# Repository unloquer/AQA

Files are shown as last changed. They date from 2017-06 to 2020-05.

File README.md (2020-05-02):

## Agentes de la Calidad del Aire (AQA)
Cuando se desea profundizar en el problema de la calidad del aire en Medellín nos encontramos con varios obstáculos debido a la complejidad del problema y la limitada capacidad de los ciudadanos para recolectar y examinar las mediciones.
El Kit AQA se esfuerza por acercar al ciudadano a la posibilidad de medir y analizar el aire que respira. De hecho, en las actividades propuestas se aprende a ensamblar un dispositivo para la medición del materialparticulado, y se considera unas herramientas para el estudio de las mediciones.
Es en los detalles del ensamblaje y el uso de las herramientas de análisis donde se puede pensar con las manos y entrar en relación directa con el problema de la calidad del aire.

## Instalación

descargar repositorio

          git clone https://github.com/unloquer/AQA.git

https://comunidad.unloquer.org/t/como-programar-el-aqa/33

## Enlaces
  * [Ejemplo de la trama de datos](https://raw.githubusercontent.com/daquina-io/VizCalidadAire/master/data/points.csv) https://raw.githubusercontent.com/daquina-io/VizCalidadAire/master/data/points.csv
  * [Foro](https://comunidad.unloquer.org/) comunidad unloquer  https://comunidad.unloquer.org/
  * [wiki](http://wiki.unloquer.org/personas/brolin/proyectos/agentes_calidad_aire) wiki unloquer http://wiki.unloquer.org/personas/brolin/proyectos/agentes_calidad_aire
  * [mapa de mediciones](http://daquina.io/aqaviz/) daquia.io http://daquina.io/aqaviz/
  * [Licensed under the TAPR Open Hardware License](www.tapr.org/OHL): www.tapr.org/OHL

## Como leer los colores
el color gradiente de los leds funciona mientras mas intenso el color mas contaminacion  y menos inteso el color  menos contaminacion

el color gradiente de los leds funciona mientras mas intenso el color mas contaminacion y menos inteso el color menos contaminacion 

color > 13 resultado genrlamente verde 

13 < color < 35 resultado  generamente amarillo

35 < color < 55 resultado  generalmente naranja

55 < color < 75 resultado  generalmente rojo

75 < color < 255 resultado  generalmente morado

color < 255 marron

## para donde van los datos

  * [mapa de mediciones](http://daquina.io/aqaviz/) daquia.io http://daquina.io/aqaviz/
  * [los dash board](http://aqa.unloquer.org:8888/sources/2/chronograf/data-explorer) chronograf http://aqa.unloquer.org:8888/sources/2/chronograf/data-explorer

## de donde vienen los datos de de difentes sensores como 

 * dht11 
 * plantower 
 * gps

## pines 
diagrama de pines

## como lo instalo 

[enlace a como instalarlo en comunidad unloquer](https://comunidad.unloquer.org/t/cargar-el-firmware-desde-linea-de-comando/118) 

## contacto 

 * irc --> #un/loquer
 * twitter --> [twitter de unloquer](https://twitter.com/unloquer?lang=es) enlace a https://twitter.com/unloquer?lang=es

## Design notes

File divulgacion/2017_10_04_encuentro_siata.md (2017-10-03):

# Encuentro con SIATA

## ¿Cómo estamos enfrentando el problema en un/loquer?
### El más bajo costo posible
### Comunidad alrededor del problema
  
  * ¿Blockchain? inmutable, consenso, retribución a los participantes
  
### Motivaciones
  * Tener datos para poder "jugar" 
  * Aprender de sensores y sistemas complejos
  
### Uso social de los de los datos como alternativa a la cultura de hacer emprendimientos comerciales de los datos

  * Permite acciones que respondan a necesidades directas (excursiones de toma de datos en situaciones críticas) 
  * Invitar a la acción colectiva a partir de los datos.

### Documentar con soberanía
  * facebook vs. datos publicos distribuidos
    - blockstack
    
### Gobierno distribuido

## Lo que nos gustaría aprender del SIATA
  * ¿Son reproducibles las nubecitas? (codigo abierto y diagrama de cableado)
  * ¿Vale la pena medir los gases?
  
## Propuestas
  * ¿Podríamos instalar uno de los sensores que estamos construyendo en una de las estaciones para comparar las mediciones? si usamos la ecuación descrita en https://en.wikipedia.org/wiki/Air_quality_index#Computing_the_AQI  podrían ser comparables las lecturas?

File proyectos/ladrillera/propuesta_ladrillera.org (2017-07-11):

* Agentes Calidad del Aire
** Justificación
   Medellín tiene un problema de calidad del aire, la política pública tiene planes a largo plazo, el sistema publico de monitoreo de calidad del aire tiene alcance limitado. 
** Problema
   El ciudadano no tiene una medición del aire que respira en el momento. 
** Solución propuesta
   Medidor portable que indique visualmente la calidad del aire y que permita socializar esas mediciones.
** Fases
*** Primer fase: 
**** Puntos fijos
**** con plataforma web de captura de datos,
**** alimentación de energía 
**** transmisión vía WiFi
**** (Opción almacenaje de datos en SD?)
**** Uso de los datos:
***** a. Publicación de dataset (Open Data), sin procesamiento o con depuración??
***** b. Publicación básica de resultados en web responsive, en mapas y capas de análisis básico.
**** Presupuesto fase 1:
     :LOGBOOK:
     CLOCK: [2017-07-10 Mon 17:40]--[2017-07-10 Mon 18:30] =>  0:50
     :END:
| Payee                                 | Account                                          | Amount   | Balance     |
| Sensor de partículas                  | fase1:costo:aparato:componente:sensor            | $ -20.00 | $ -20.00    |
| ESP8266                               | fase1:costo:aparato:componente:esp               | $ -10.00 | $ -30.00    |
| DHT (sensor de humedad y temperatura) | fase1:costo:aparato:componente:sensor:dht        | $ -0.65  | $ -30.65    |
| Leds                                  | fase1:costo:aparato:componente:feedback:led      | $ -0.16  | $ -30.81    |
| Alimentación Energía                  | fase1:costo:aparato:componente:energia:adaptador | $ -6.00  | $ -36.81    |
| Ensamblaje                            | fase1:costo:aparato:manoDeObra:ensamblaje        | $ -17.00 | $ -53.81    |
| Diseño electrónico                    | fase1:costo:aparato:manoDeObra:diseno            | $ -17.00 | $ -70.81    |
| Cableado                              | fase1:costo:aparato:manoDeObra:cableado          | $ -1.00  | $ -71.81    |
| Carcasa                               | fase1:costo:aparato:manoDeObra:diseno:carcasa    | $ -20.00 | $ -91.81    |
| Código                                | fase1:costo:aparato:manoDeObra:codigo            | $ -10.00 | $ -101.81   |
| Infraestructura                       | fase1:costo:aparato:infraestructura              | $ -12.00 | $ -113.81   |
|---------------------------------------+--------------------------------------------------+----------+-------------|
| Impuestos IVA 19%                     | fase1:costo:aparato:impuestos                    | $ -21.47 | $ -135.28   |
| Utilidad                              | fase1:costo:aparato:utilidad                     | $ -22.60 | $ -157.88   |
|---------------------------------------+--------------------------------------------------+----------+-------------|
|                                       |                                                  | Total    | $ -157.88   |

***  Segunda Fase: 
**** Puntos móviles con gps (Batería, 
**** transmisión vía WiFi o SimCard?, 
**** (opción de almacenar en SD).
**** Uso de los datos:
***** a. Publicación de dataset (Open Data), sin procesamiento o con depuración??
***** b. Publicación básica de resultados en web responsive, en mapas y capas de análisis básico.
***** c. Desarrollo de aplicación móvil (Android, posiblemente ios).
**** Presupuesto fase 2:
     :LOGBOOK:
     CLOCK: [2017-07-11 Tue 05:05]
     :END:
| Payee                                 | Account                                          | Amount   | Balance     |
| ESP8266                               | fase2:costo:aparato:componente:esp               | $ -10.00 | $ -10.00    |
| Sensor de partículas                  | fase2:costo:aparato:componente:sensor            | $ -20.00 | $ -30.00    |
| Gps                                   | fase2:costo:aparato:componente:gps               | $ -12.00 | $ -42.00    |
| DHT (sensor de humedad y temperatura) | fase2:costo:aparato:componente:sensor:dht        | $ -0.65  | $ -42.65    |
| Leds                                  | fase2:costo:aparato:componente:feedback:led      | $ -0.16  | $ -42.81    |
| Alimentación Energía                  | fase2:costo:aparato:componente:energia:adaptador | $ -6.00  | $ -48.81    |
| Batería                               | fase2:costo:aparato:componente:energia:bateria   | $ -6.00  | $ -54.81    |
| Ensamblaje                            | fase2:costo:aparato:manoDeObra:ensamblaje        | $ -17.00 | $ -71.81    |
| Diseño electrónico                    | fase2:costo:aparato:manoDeObra:diseno            | $ -17.00 | $ -88.81    |
| Cableado                              | fase2:costo:aparato:manoDeObra:cableado          | $ -1.00  | $ -89.81    |
| Carcasa                               | fase2:costo:aparato:manoDeObra:diseno:carcasa    | $ -20.00 | $ -109.81   |
| Código backend                        | fase2:costo:aparato:manoDeObra:codigo            | $ -10.00 | $ -119.81   |
| Análisis-Mapas                        | fase2:costo:servicio:analisis:mapas              | $ -10.00 | $ -129.81   |
| Aplicación móvil Android              | fase2:costo:servicio:aplicacion:android          | $ -10.00 | $ -139.81   |
| Lector memoria SD                     | fase2:costo:aparato:componente:lectorSD          | $ -0.66  | $ -140.47   |
| Infraestructura                       | fase2:costo:aparato:infraestructura              | $ -12.00 | $ -152.47   |
|---------------------------------------+--------------------------------------------------+----------+-------------|
| Impuestos IVA 19%                     | fase2:costo:aparato:impuestos                    | $ -28.88 | $ -181.35   |
| Utilidad                              | fase2:costo:aparato:utilidad                     | $ -30.40 | $ -211.75   |
|---------------------------------------+--------------------------------------------------+----------+-------------|
|                                       |                                                  | Total    | $ -211.75   |

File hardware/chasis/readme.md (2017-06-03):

Todos estos archivos abren con Solidworks y con Solidcam. Contactar a @rvega si necesitan el software o convertir de formato.

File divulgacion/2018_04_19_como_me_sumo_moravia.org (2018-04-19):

#+TITLE:      ¿Cómo me sumo?
#+AUTHOR:     son0p (Federico López)
#+EMAIL:      fede2001@gmail.com
#+INFOJS_OPT: view:t toc:t ltoc:t mouse:underline buttons:0 path:http://thomasf.github.io/solarized-css/org-info.min.js
#+HTML_HEAD: <link rel="stylesheet" type="text/css" href="http://thomasf.github.io/solarized-css/solarized-light.min.css" />
#+OPTIONS:    H:3 num:nil toc:t \n:nil ::t |:t ^:t -:t f:t *:t tex:t d:(HIDE) tags:not-in-toc
#+STARTUP:    align fold nodlcheck hidestars oddeven lognotestate
#+SEQ_TODO:   TODO(t) INPROGRESS(i) WAITING(w@) | DONE(d) CANCELED(c@)
#+LANGUAGE:   en
#+PRIORITIES: A C B
#+CATEGORY:   divulgacion

* ¿Cómo se esta sumando unloquer al problema de la calidad del aire?
** ¿Es relevante un dispositivo que le muestre a la *persona* la calidad del aire que respira en *ese  momento*?
** ¿De que sirve compartir esas mediciones a una red ciudadana?
*** ¿Los datos históricos me permiten enterarme de los momentos (meses, dias, horas) en que mejora la calidad del aire?
** ¿Qué poder tengo sobre mi aire?
*** ¿Las personas que estan tomando desiciones para cambiar esa situación estan muy lejos?
*** ¿A qué velocidad podemos esperar los cambios?
*** ¿Sirve la metáfora de la reja ? 
    Una persona habita con una ventana en un primer piso que da a la calle, a varios vecinos les han roto la ventana para robarles frutas y otras pertenencias, el gobierno dice que tiene pactos y programas para disminuír la delincuencia en la ciudad gradualmente hasta lograr índices parecidos a alguna ciudad tranquila de un país desarrollado, la persona no sabe si esperar a que el gobierno mejore la inseguridad o poner una reja en su ventana.
*** ¿La máscara sírve?                                                   
**** ¿Las partículas pm25 son mas pequeñas que un pelo de la nariz? 25 a 70 :log:
*** ¿Puedo saber dónde esta mejor el aire?

** ¿Puedo usar el pretexto del problema de la calidad del aire en medellín para aprender de  matemáticas?
*** ¿De Antropología?
**** ¿Es un problema nuevo en la ciudad? ¿no?  http://www.universocentro.com/NUMERO86/Humossetenteros.aspx
*** ¿De Programación?
*** ¿De Biología? 
**** El Guáimaro, Sogamoso https://actualidad.rt.com/actualidad/266121-arbol-magico-colombia-titan-polucion
** ¿Cómo me sumo?
*** ¿Puedo donar un sensor a un hospital infantil?
*** ¿Puedo resolver alguno de los problemas de programación?  https://github.com/unloquer/AQA/issues
*** ¿Puedo medir la calidad del aire en una fábrica cerca a mi casa?
*** ¿Puedo ayudar a saber si los foggers sirven para disminuir el material particulado?
*** ¿Puedo conversar sobre el tema en un foro? https://comunidad.unloquer.org/
* ------

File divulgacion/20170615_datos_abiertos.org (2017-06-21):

#+TITLE:      De los personal a lo colectivo
#+AUTHOR:     un/loquer
#+EMAIL:      unloquer@gmail.com
#+OPTIONS:    H:2 num:nil toc:t \n:nil ::t |:t ^:t -:t f:t *:t tex:t d:(HIDE) tags:not-in-toc
#+STARTUP:    align fold nodlcheck hidestars oddeven lognotestate
#+SEQ_TODO:   TODO(t) INPROGRESS(i) WAITING(w) | DONE(d) CANCELED(c)
#+TAGS:       Write(w) Update(u) Fix(f) Check(c) 
#+LANGUAGE:   es
#+PRIORITIES: A C B
#+CATEGORY:   un/loquer
#+CONSTANTS: d=298

** ¿Qué vamos a aprender hoy?
*** ¿Cómo en un/loquer se esta respondiendo ante el problema del aire?
**** ¿Artefacto para medir y reportar?
     Un dispositivo que permite hacer mediciones móviles.
***** ¿Microcontrolador? *ESP8266*
      Tiene conectividad wi-fi integrada, recive los datos de direferentes protocolos y genera la trama de datos.

|      lat |        lng | date      |        hour | altitude | course | speed | humidity | temperature | pm1 | pm25 | pm10 |
| 6.254207 | -75.575022 | 5/11/2017 | 05:54:00.00 |   1498.5 | 189.57 | 14.24 |     34.0 |        28.0 |  11 |   16 |   17 |
| 6.253995 | -75.575045 | 5/11/2017 | 05:54:05.00 |   1499.1 | 179.03 | 15.26 |     34.0 |        28.0 |  11 |   16 |   17 |
| 6.253763 | -75.575067 | 5/11/2017 | 05:54:11.00 |   1498.8 | 186.22 | 14.46 |     34.0 |        28.0 |  11 |   16 |   17 |
| 6.253593 | -75.575132 | 5/11/2017 | 05:54:16.00 |   1497.9 | 215.65 | 12.45 |     34.0 |        28.0 |  11 |   16 |   17 |
| 6.253485 | -75.575307 | 5/11/2017 | 05:54:22.00 |   1498.3 | 256.68 | 14.41 |     34.0 |        28.0 |  11 |   16 |   17 |
| 6.253502 | -75.575495 | 5/11/2017 | 05:54:27.00 |   1498.2 |  296.0 | 14.89 |     34.0 |        28.0 |  11 |   16 |   17 |

****** ¿Almacena los datos?
       Sí, porque no podemos garantizar conectividad wi-fi, se está trabajando en implementar el reporte a travéz de una red LoRa
***** ¿GPS?  *quectel l70*
      Entrega Timestamp, Latitud, Longitud, Altitud, Curso, y Velocidad, ver issue https://github.com/unloquer/AQA/issues/18
*****  ¿Sensor de partículas? *planttower PMSx003*
      Entrega mediciones de partículas pm1, pm2.5 y pm10.
***** ¿Sensor de temperatura y humedad? *DHT11*
***** ¿RGB Leds? 
      Retroalimentación visual expresada en colores ajustada a alguna escala.
***** TODO ¿Carcasa?
**** ¿Compartir los datos capturados?
*****  ¿Prueba de concepto? 
      Actualmente los datos se descargan de la memoria Flash de forma rudimentaria.
***** ¿Compartir la medición PM2.5 usando el ESSID?  
      Cualquier dispositivo Wi-Fi al alcance puede recibir el reporte de la medición en su listado de redes disponibles. https://github.com/unloquer/AQA/issues/14
***** TODO ¿Descarga con Wi-Fi?
      Requiere un navegador para conectar el ESP a alguna red disponible.
***** TODO ¿LoRa?
      Estamos en la búsqueda de unos gateway para hacer una prueba de concepto.
**** Detonantes:
***** Cuanto le vale a la ciudad darle información al individuo de su entorno vs. Cuanto le vale al individo generar esa info
***** ¿Aprendizaje a travez de problemas? *** ¿aprender? ¿en serio?
****** anarquía; no reconoce autoridad, paternalismo, ¿Qué hacemos?
****** varias ligas                                                     :Fix:
******* escala ciudad 
******* escala personal
*** ¿Qué puedo aprender con los datos que exponen?
**** dataPoints (advertencia!)  https://raw.githubusercontent.com/daquina-io/VizCalidadAire/master/data/points.csv
*****  ¿Porqué hay una medida de 500 !!! ¿subjetiva?
      Son datos sucios por diferentes razones, algunas ideas de depuración de @kleper https://github.com/daquina-io/VizCalidadAire/issues/2
****** ¿Cómo podemos calibrar? https://github.com/unloquer/AQA/issues/13
****** Link a mediciones mayores a 100 http://daquina.io/aqaviz/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
****** ¿Y si le agregamos un consenso? 
       Tener muchas mediciones del mismo sitio en diferentes días y horas permitiría ir validando los datos.
****** Gps 
       Emite datos errados cuando se está localizando, el asunto se esta tratando acá: https://github.com/unloquer/AQA/issues/18

**** Detonantes
***** ¿Puedo hacer mi propia comunidad de aire?
****** ¿Porque comunidades pequeñas?
***** ¿Puedo poner historias ?
*** ¿De qué me sirve los aspectos "abiertos" de lo que están haciendo?
**** ¿Respecto al Firmware? 
***** ¿Puedo adaptar el código a mis necesidades?
***** ¿Puedo quitar o agregar componentes (micrófono)?
**** ¿Respecto al Hardware?                                           :Check:
***** ¿Puedo cambiar el diseño PCB? ¿Para qué?
***** ¿Diseño sensor?                                                 :Check:
***** ¿Microcontrolador ESP2688?                                      :Check:
**** ¿Se puede alterar los datos?
***** ¿blame? ¿cadena de custodia? ¿blockchain?
**** ¿Porqué publican el presupuesto? https://github.com/unloquer/AQA/blob/master/costos.dat    

     | Dispositivo               | us$ |   col$ |
     |---------------------------+-----+--------|
     | DIY                       |  44 | 128876 |
     | Muñeco, cables a la vista | 108 | 316332 |
     | Embebido en carcasa       | 178 | 521362 |
     #+TBLFM: $3=$2*2929

**** Documentacion
***** Repositorio  https://github.com/unloquer/AQA
****** Fork
****** Clone
****** Pull request
****** Blame
***** Wiki http://wiki.unloquer.org/personas/brolin/proyectos/agentes_calidad_aire
**** Asuntos / issues / problemas https://github.com/unloquer/AQA/issues
**** ¿ lo puedo cerrar y vender?
***** ¿licenciar para mantener abierto?
****** ¿TAPR?  http://www.tapr.org/OHL
**** Detonantes
***** ¿Para que dure más de 100 años debe ser abierto o cerrado?

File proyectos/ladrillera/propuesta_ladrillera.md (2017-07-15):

<div id="table-of-contents">
<h2>Table of Contents</h2>
<div id="text-table-of-contents">
<ul>
<li><a href="#org6e1e0bf">1. Agentes Calidad del Aire</a>
<ul>
<li><a href="#org526cd84">1.1. Justificación</a></li>
<li><a href="#orge21955c">1.2. Problema</a></li>
<li><a href="#orgf99aaa4">1.3. Solución propuesta</a></li>
<li><a href="#org3859f35">1.4. Fases</a>
<ul>
<li><a href="#orgd3f207a">1.4.1. Primer fase:</a></li>
<li><a href="#org5c07fcc">1.4.2. Segunda Fase:</a></li>
</ul>
</li>
</ul>
</li>
</ul>
</div>
</div>

# Agentes Calidad del Aire

## Justificación

El Valle de Aburrá sufre un problema de acción colectiva en cuanto a la calidad del aire, pues, además de una topografía poco favorable para dispersar los gases contaminantes que la ciudad emite cada día, no existe un mecanismo que permita evidenciar el costo de las externalidades negativas por emisión de gases, así como los responsables directos de las mismas. Esto origina debilidad en el entendimiento del problema mismo, las políticas públicas no son capaces de hacer frente a la situación y se produce de forma generalizada la situación de "free-riders". La realidad es que no todos contaminamos igual, pero todos sí sufrimos las consecuencias de un aire en mal estado. 

Los efectos en la salud pública son la muestra más visible y urgente del problema. Estudios del Departamento Nacional de Planeación (DNP) revelan que la contaminación del aire urbano aporta el 75% de los gastos al sistema de salud colombiano por muertes y enfermedades asociadas a la degradación ambiental en Colombia, es decir, cerca de 15,4 billones de pesos. Esto significa 10 mil 527 personas entre 2015 y 2016 por esta causa. La ciudad con mayor número de casos es Medellín, con 2.105, que representan el 12,3 por ciento del total de las muertes que se presentan en esa ciudad. Esto representa un costo para la capital antioqueña de 2,8 billones de pesos, equivalentes al 5 por ciento del PIB de su Área Metropolitana. 

Las mediciones del Área Metropolitana del Valle de Aburrá muestran que 79% de las emisiones de PM 2.5, la partícula de contaminación más dañina para el ser humana, provienen de las fuentes móviles. Si bien se conoce que la solución de más impacto es la renovación del parque automotor más contaminante, el problema político inherente está en quién debe asumir el costo de esa renovación. Un primer paso está en el reconocimiento del problema, como ya hoy lo permite el Siata, pero este sistema de monitoreo es limitado pues no permite conocer el detalles claves del problema como los lugares precisos que presentan más contaminación, la calidad del aire que efectivamente están respirando las personas y los responsables directos. 

A raíz de esta situación, en marzo de 2017 el colectivo Datos y Gobierno Abierto Medellín realizó una jornada de trabajo durante el 'Open Data Day Medellin' (goo.gl/wacA5X), en la que se priorizaron los siguientes puntos como espacios de oportunidad para la generación de soluciones a la contaminación del aire:
1. La falta de información pública en términos de datos abiertos respecto a la calidad del aire y sus problemáticas conexas. Esto repercute en la dificultad para reconocer el problema y sus evidencias, además de hacer menos transparente el proceso de gestión de calidad del aire.
2. La falta de iniciativas pedagógicas dirigidas a la ciudadanía para que pueda aprender, comprender y proponer frente a la problemática actual del aire.
3. La falta de sensores y dispositivos ciudadanos de bajo costo que contribuyan a la captura, procesamiento y análisis de información sobre la calidad del aire.

## Problema

Con base en lo anterior, esta propuesta apunta a la generación de una solución para el ciudadano que no tiene una medición del aire que respira en el momento, así como la falta de datos de detalle sobre la calidad de aire que efectivamente respiran los habitantes de la ciudad. 

## Solución propuesta

Medidor portable que indique visualmente la calidad del aire y que permita agregar esas mediciones en una plataforma pública en línea con funcionalidades para el análisis de datos.

## Fases

### Primer fase:

1.  Puntos fijos

2.  con plataforma web de captura de datos,

3.  alimentación de energía

4.  transmisión vía WiFi

5.  (Opción almacenaje de datos en SD?)

6.  Uso de los datos:

    1.  a. Publicación de dataset (Open Data), sin procesamiento o con depuración??
    
    2.  b. Publicación básica de resultados en web responsive, en mapas y capas de análisis básico.

7.  Presupuesto fase 1:

    <table border="2" cellspacing="0" cellpadding="6" rules="groups" frame="hsides">

    <colgroup>
    <col  class="org-left" />
    
    <col  class="org-left" />
    
    <col  class="org-left" />
    
    <col  class="org-left" />
    </colgroup>
    <thead>
    <tr>
    <th scope="col" class="org-left">Payee</th>
    <th scope="col" class="org-left">Account</th>
    <th scope="col" class="org-left">Amount</th>
    <th scope="col" class="org-left">Balance</th>
    </tr>

    <tr>
    <th scope="col" class="org-left">Sensor de partículas</th>
    <th scope="col" class="org-left">fase1:costo:aparato:componente:sensor</th>
    <th scope="col" class="org-left">$ -20.00</th>
    <th scope="col" class="org-left">$ -20.00</th>
    </tr>

    <tr>
    <th scope="col" class="org-left">ESP8266</th>
    <th scope="col" class="org-left">fase1:costo:aparato:componente:esp</th>
    <th scope="col" class="org-left">$ -10.00</th>
    <th scope="col" class="org-left">$ -30.00</th>
    </tr>

    <tr>
    <th scope="col" class="org-left">DHT (sensor de humedad y temperatura)</th>
    <th scope="col" class="org-left">fase1:costo:aparato:componente:sensor:dht</th>
    <th scope="col" class="org-left">$ -0.65</th>
    <th scope="col" class="org-left">$ -30.65</th>
    </tr>

    <tr>
    <th scope="col" class="org-left">Leds</th>
    <th scope="col" class="org-left">fase1:costo:aparato:componente:feedback:led</th>
    <th scope="col" class="org-left">$ -0.16</th>
    <th scope="col" class="org-left">$ -30.81</th>
    </tr>

    <tr>
    <th scope="col" class="org-left">Alimentación Energía</th>
    <th scope="col" class="org-left">fase1:costo:aparato:componente:energia:adaptador</th>
    <th scope="col" class="org-left">$ -6.00</th>
    <th scope="col" class="org-left">$ -36.81</th>
    </tr>

    <tr>
    <th scope="col" class="org-left">Ensamblaje</th>
    <th scope="col" class="org-left">fase1:costo:aparato:manoDeObra:ensamblaje</th>
    <th scope="col" class="org-left">$ -17.00</th>
    <th scope="col" class="org-left">$ -53.81</th>
    </tr>

    <tr>
    <th scope="col" class="org-left">Diseño electrónico</th>
    <th scope="col" class="org-left">fase1:costo:aparato:manoDeObra:diseno</th>
    <th scope="col" class="org-left">$ -17.00</th>
    <th scope="col" class="org-left">$ -70.81</th>
    </tr>

    <tr>
    <th scope="col" class="org-left">Cableado</th>
    <th scope="col" class="org-left">fase1:costo:aparato:manoDeObra:cableado</th>
    <th scope="col" class="org-left">$ -1.00</th>
    <th scope="col" class="org-left">$ -71.81</th>
    </tr>

    <tr>
    <th scope="col" class="org-left">Carcasa</th>
    <th scope="col" class="org-left">fase1:costo:aparato:manoDeObra:diseno:carcasa</th>
    <th scope="col" class="org-left">$ -20.00</th>
    <th scope="col" class="org-left">$ -91.81</th>
    </tr>

    <tr>
    <th scope="col" class="org-left">Código</th>
    <th scope="col" class="org-left">fase1:costo:aparato:manoDeObra:codigo</th>
    <th scope="col" class="org-left">$ -10.00</th>
    <th scope="col" class="org-left">$ -101.81</th>
    </tr>

    <tr>
    <th scope="col" class="org-left">Infraestructura</th>
    <th scope="col" class="org-left">fase1:costo:aparato:infraestructura</th>
    <th scope="col" class="org-left">$ -12.00</th>
    <th scope="col" class="org-left">$ -113.81</th>
    </tr>
    </thead>
    
    <tbody>
    <tr>
    <td class="org-left">Impuestos IVA 19%</td>
    <td class="org-left">fase1:costo:aparato:impuestos</td>
    <td class="org-left">$ -21.47</td>
    <td class="org-left">$ -135.28</td>
    </tr>

    <tr>
    <td class="org-left">Utilidad</td>
    <td class="org-left">fase1:costo:aparato:utilidad</td>
    <td class="org-left">$ -22.60</td>
    <td class="org-left">$ -157.88</td>
    </tr>
    </tbody>
    
    <tbody>
    <tr>
    <td class="org-left">&#xa0;</td>
    <td class="org-left">&#xa0;</td>
    <td class="org-left">Total</td>
    <td class="org-left">$ -157.88</td>
    </tr>
    </tbody>
    </table>

### Segunda Fase:

1.  Puntos móviles con gps (Batería,

2.  transmisión vía WiFi o SimCard?,

3.  (opción de almacenar en SD).

4.  Uso de los datos:

    1.  a. Publicación de dataset (Open Data), sin procesamiento o con depuración??
    
    2.  b. Publicación básica de resultados en web responsive, en mapas y capas de análisis básico.
    
    3.  c. Desarrollo de aplicación móvil (Android, posiblemente ios).

5.  Presupuesto fase 2:

    <table border="2" cellspacing="0" cellpadding="6" rules="groups" frame="hsides">

    <colgroup>
    <col  class="org-left" />
    
    <col  class="org-left" />
    
    <col  class="org-left" />
    
    <col  class="org-left" />
    </colgroup>
    <thead>
    <tr>
    <th scope="col" class="org-left">Payee</th>
    <th scope="col" class="org-left">Account</th>
    <th scope="col" class="org-left">Amount</th>
    <th scope="col" class="org-left">Balance</th>
    </tr>

    <tr>
    <th scope="col" class="org-left">ESP8266</th>
    <th scope="col" class="org-left">fase2:costo:aparato:componente:esp</th>
    <th scope="col" class="org-left">$ -10.00</th>
    <th scope="col" class="org-left">$ -10.00</th>
    </tr>

    <tr>
    <th scope="col" class="org-left">Sensor de partículas</th>
    <th scope="col" class="org-left">fase2:costo:aparato:componente:sensor</th>
    <th scope="col" class="org-left">$ -20.00</th>
    <th scope="col" class="org-left">$ -30.00</th>
    </tr>

    <tr>
    <th scope="col" class="org-left">Gps</th>
    <th scope="col" class="org-left">fase2:costo:aparato:componente:gps</th>
    <th scope="col" class="org-left">$ -12.00</th>
    <th scope="col" class="org-left">$ -42.00</th>
    </tr>

    <tr>
    <th scope="col" class="org-left">DHT (sensor de humedad y temperatura)</th>
    <th scope="col" class="org-left">fase2:costo:aparato:componente:sensor:dht</th>
    <th scope="col" class="org-left">$ -0.65</th>
    <th scope="col" class="org-left">$ -42.65</th>
    </tr>

    <tr>
    <th scope="col" class="org-left">Leds</th>
    <th scope="col" class="org-left">fase2:costo:aparato:componente:feedback:led</th>
    <th scope="col" class="org-left">$ -0.16</th>
    <th scope="col" class="org-left">$ -42.81</th>
    </tr>

    <tr>
    <th scope="col" class="org-left">Alimentación Energía</th>
    <th scope="col" class="org-left">fase2:costo:aparato:componente:energia:adaptador</th>
    <th scope="col" class="org-left">$ -6.00</th>
    <th scope="col" class="org-left">$ -48.81</th>
    </tr>

    <tr>
    <th scope="col" class="org-left">Batería</th>
    <th scope="col" class="org-left">fase2:costo:aparato:componente:energia:bateria</th>
    <th scope="col" class="org-left">$ -6.00</th>
    <th scope="col" class="org-left">$ -54.81</th>
    </tr>

    <tr>
    <th scope="col" class="org-left">Ensamblaje</th>
    <th scope="col" class="org-left">fase2:costo:aparato:manoDeObra:ensamblaje</th>
    <th scope="col" class="org-left">$ -17.00</th>
    <th scope="col" class="org-left">$ -71.81</th>
    </tr>

    <tr>
    <th scope="col" class="org-left">Diseño electrónico</th>
    <th scope="col" class="org-left">fase2:costo:aparato:manoDeObra:diseno</th>
    <th scope="col" class="org-left">$ -17.00</th>
    <th scope="col" class="org-left">$ -88.81</th>
    </tr>

    <tr>
    <th scope="col" class="org-left">Cableado</th>
    <th scope="col" class="org-left">fase2:costo:aparato:manoDeObra:cableado</th>
    <th scope="col" class="org-left">$ -1.00</th>
    <th scope="col" class="org-left">$ -89.81</th>
    </tr>

    <tr>
    <th scope="col" class="org-left">Carcasa</th>
    <th scope="col" class="org-left">fase2:costo:aparato:manoDeObra:diseno:carcasa</th>
    <th scope="col" class="org-left">$ -20.00</th>
    <th scope="col" class="org-left">$ -109.81</th>
    </tr>

    <tr>
    <th scope="col" class="org-left">Código backend</th>
    <th scope="col" class="org-left">fase2:costo:aparato:manoDeObra:codigo</th>
    <th scope="col" class="org-left">$ -10.00</th>
    <th scope="col" class="org-left">$ -119.81</th>
    </tr>

    <tr>
    <th scope="col" class="org-left">Análisis-Mapas</th>
    <th scope="col" class="org-left">fase2:costo:servicio:analisis:mapas</th>
    <th scope="col" class="org-left">$ -10.00</th>
    <th scope="col" class="org-left">$ -129.81</th>
    </tr>

    <tr>
    <th scope="col" class="org-left">Aplicación móvil Android</th>
    <th scope="col" class="org-left">fase2:costo:servicio:aplicacion:android</th>
    <th scope="col" class="org-left">$ -10.00</th>
    <th scope="col" class="org-left">$ -139.81</th>
    </tr>

    <tr>
    <th scope="col" class="org-left">Lector memoria SD</th>
    <th scope="col" class="org-left">fase2:costo:aparato:componente:lectorSD</th>
    <th scope="col" class="org-left">$ -0.66</th>
    <th scope="col" class="org-left">$ -140.47</th>
    </tr>

    <tr>
    <th scope="col" class="org-left">Infraestructura</th>
    <th scope="col" class="org-left">fase2:costo:aparato:infraestructura</th>
    <th scope="col" class="org-left">$ -12.00</th>
    <th scope="col" class="org-left">$ -152.47</th>
    </tr>
    </thead>
    
    <tbody>
    <tr>
    <td class="org-left">Impuestos IVA 19%</td>
    <td class="org-left">fase2:costo:aparato:impuestos</td>
    <td class="org-left">$ -28.88</td>
    <td class="org-left">$ -181.35</td>
    </tr>

    <tr>
    <td class="org-left">Utilidad</td>
    <td class="org-left">fase2:costo:aparato:utilidad</td>
    <td class="org-left">$ -30.40</td>
    <td class="org-left">$ -211.75</td>
    </tr>
    </tbody>
    
    <tbody>
    <tr>
    <td class="org-left">&#xa0;</td>
    <td class="org-left">&#xa0;</td>
    <td class="org-left">Total</td>
    <td class="org-left">$ -211.75</td>
    </tr>
    </tbody>
    </table>

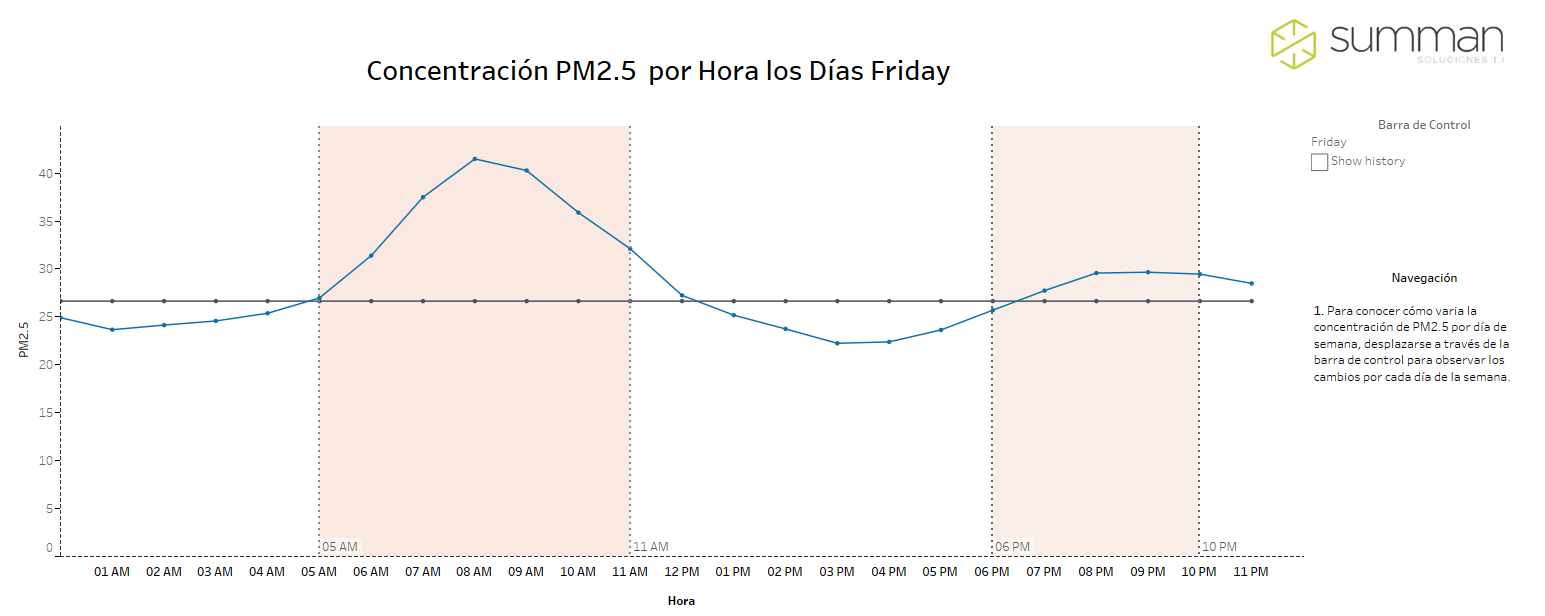
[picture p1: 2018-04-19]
divulgacion/assets/img/Día y Hora.png

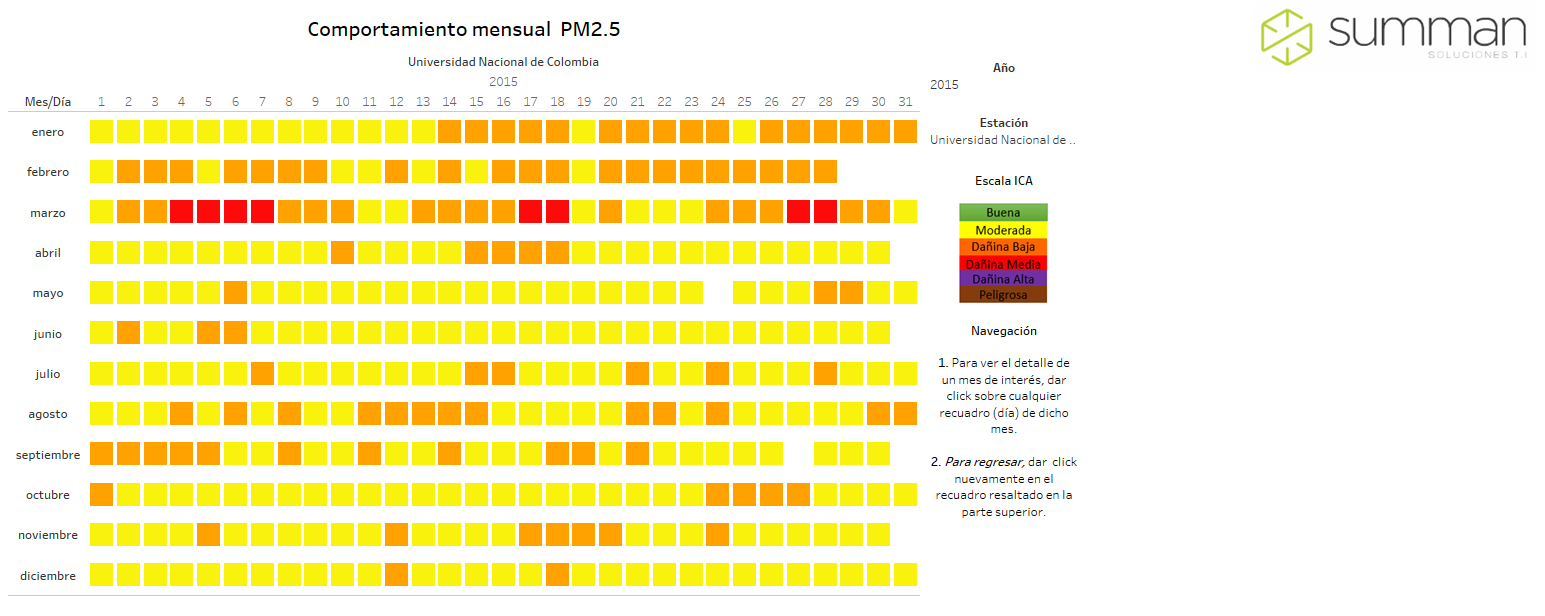
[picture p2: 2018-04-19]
divulgacion/assets/img/mes_dias.png

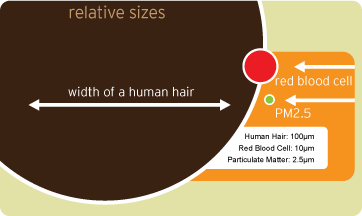
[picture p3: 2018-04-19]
divulgacion/assets/img/air-we-breathe-pm25.gif

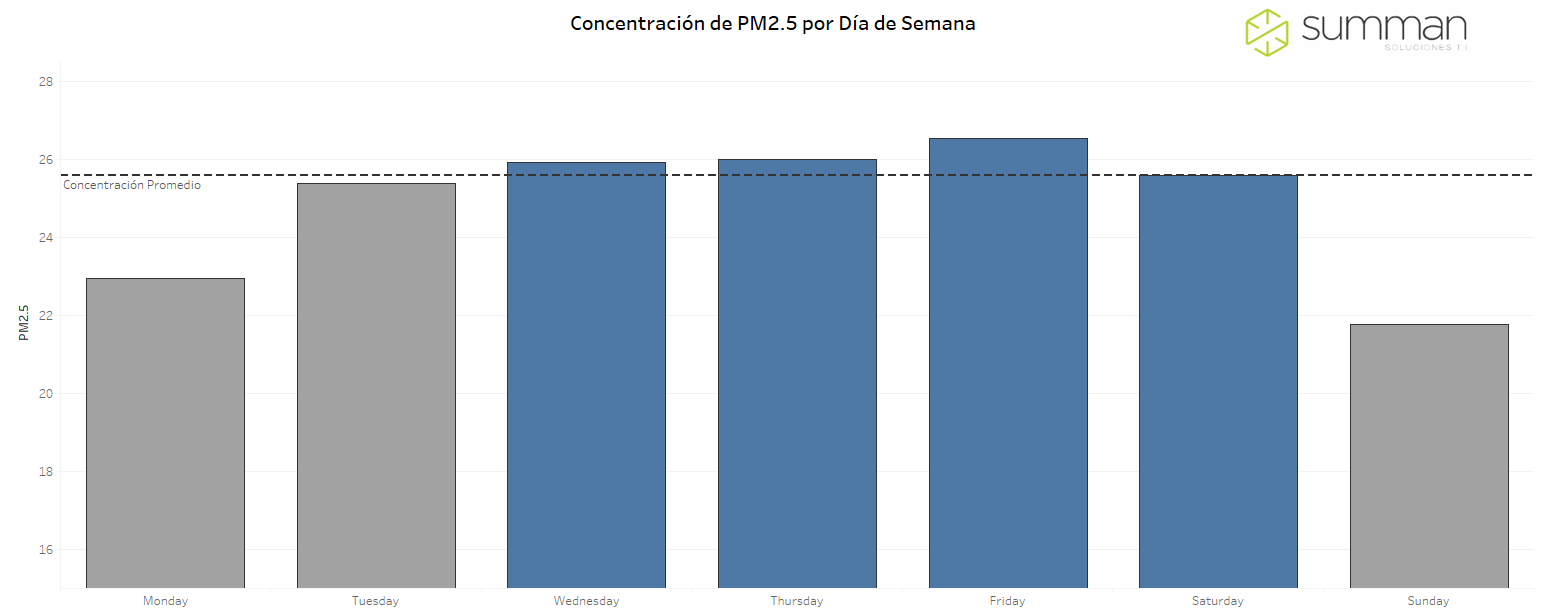
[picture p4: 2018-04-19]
divulgacion/assets/img/Semana.png

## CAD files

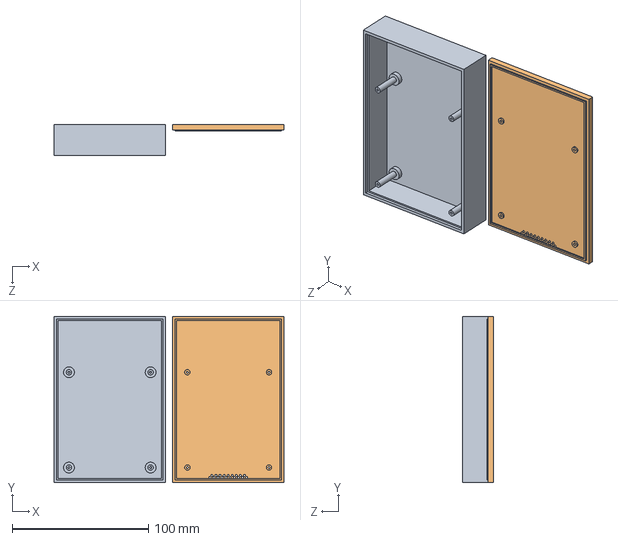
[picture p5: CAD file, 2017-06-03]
hardware/chasis/Maquinado CAM/Ensamble CAM.SLDASM
169.0 x 122.0 x 23.0 mm
Tapa1
Tapa2

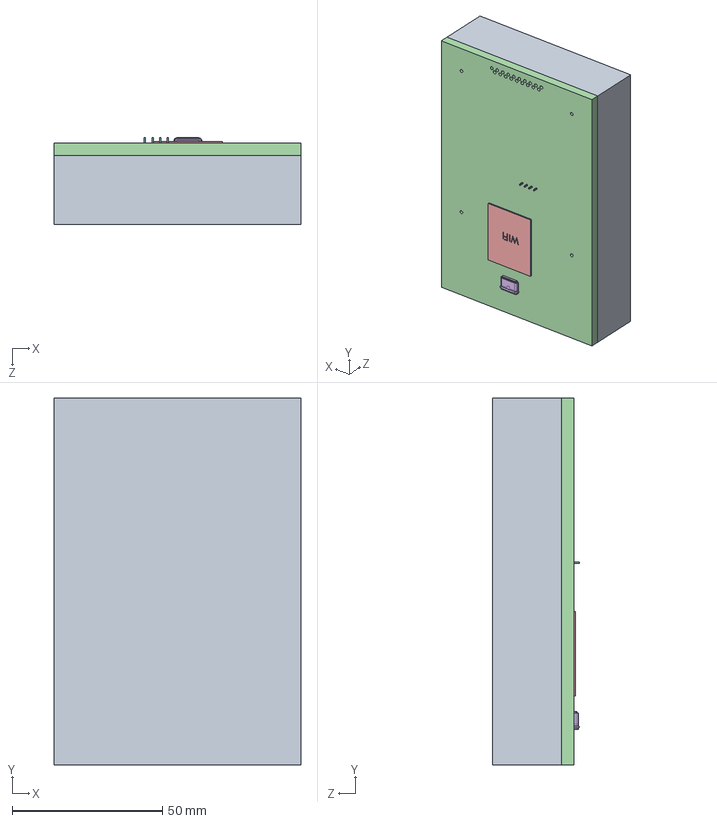
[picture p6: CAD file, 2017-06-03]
hardware/chasis/Modelo CAD/Ensamble.SLDASM
82.0 x 122.0 x 28.9 mm
Sensor
PCB
USB
GPS
DHT11

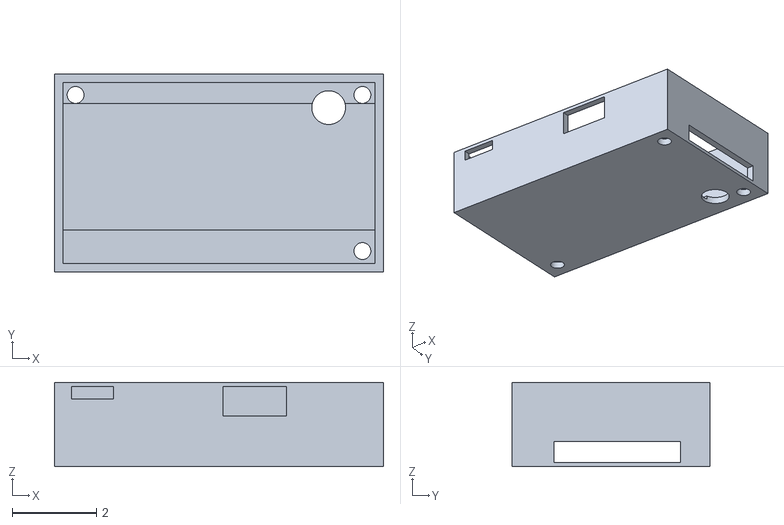
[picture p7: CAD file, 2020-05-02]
hardware/chasis/chasis_tarjeta_roja/aqacarcasa.stl
7.80 x 4.70 x 2.00

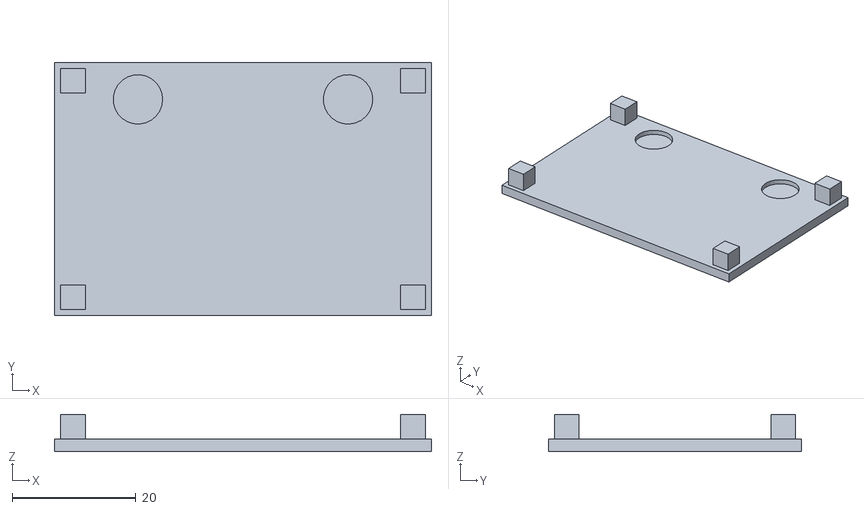
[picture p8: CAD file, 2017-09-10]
hardware/chasis/ChasisAQAFreecad/TapaChasisAQA2.stl
61.0 x 41.0 x 6.00

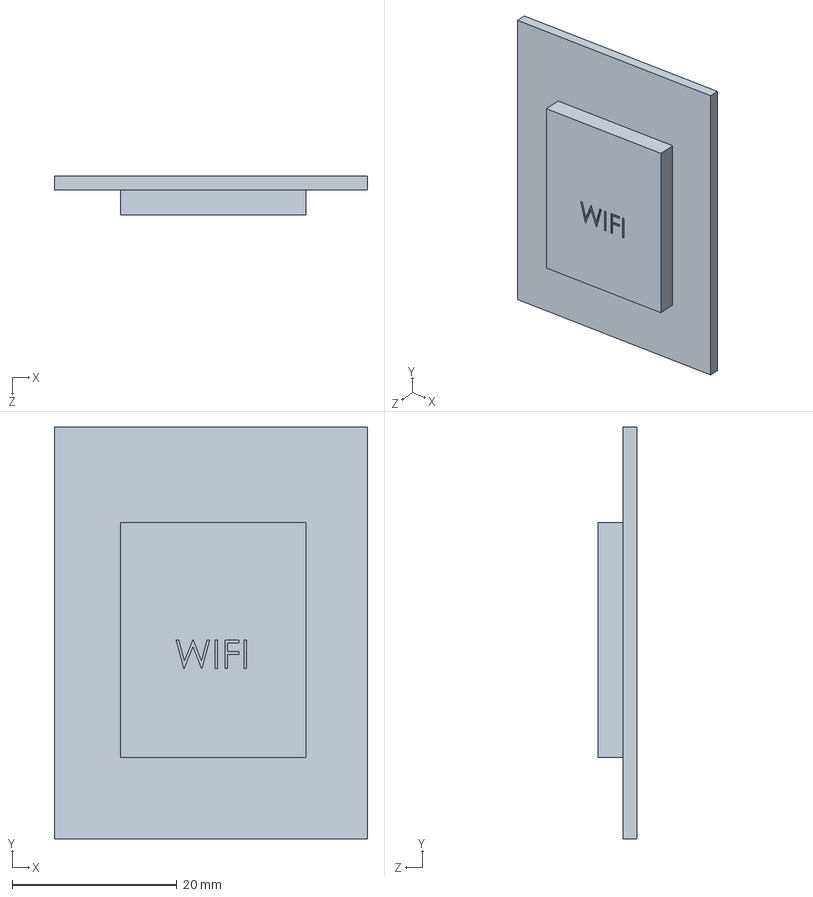
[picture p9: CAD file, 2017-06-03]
hardware/chasis/Modelo CAD/PCB.SLDPRT
38.0 x 50.0 x 4.70 mm

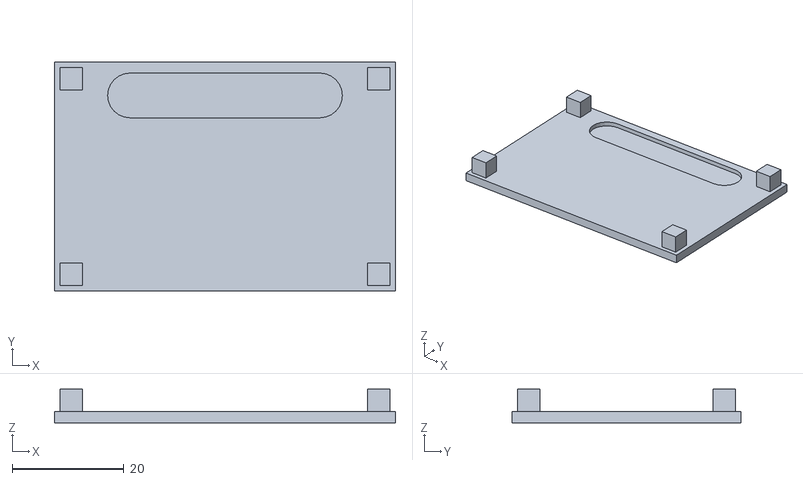
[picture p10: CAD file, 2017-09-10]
hardware/chasis/ChasisAQAFreecad/TapaChasisAQA3.stl
61.0 x 41.0 x 6.00

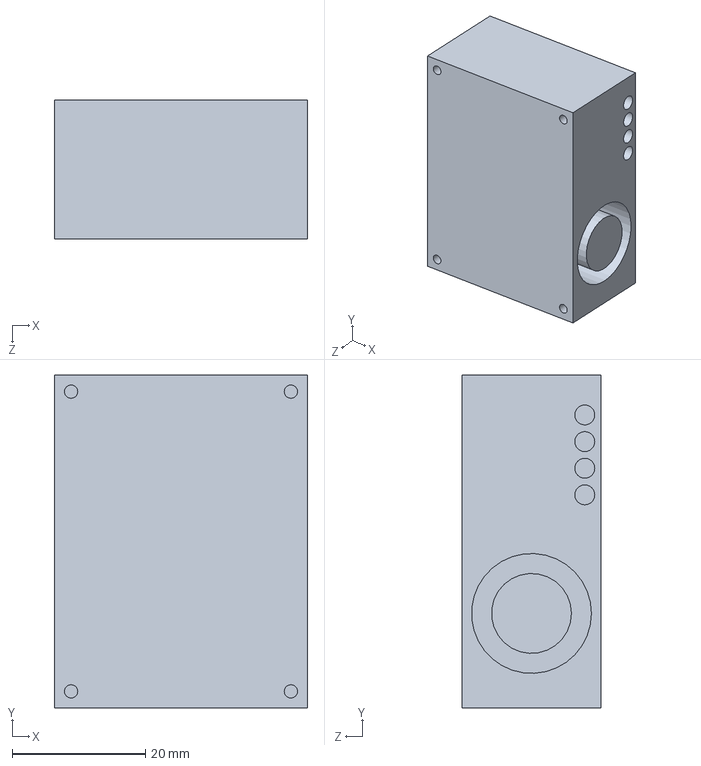
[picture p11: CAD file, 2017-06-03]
hardware/chasis/Modelo CAD/Sensor.SLDPRT
38.0 x 50.0 x 20.9 mm

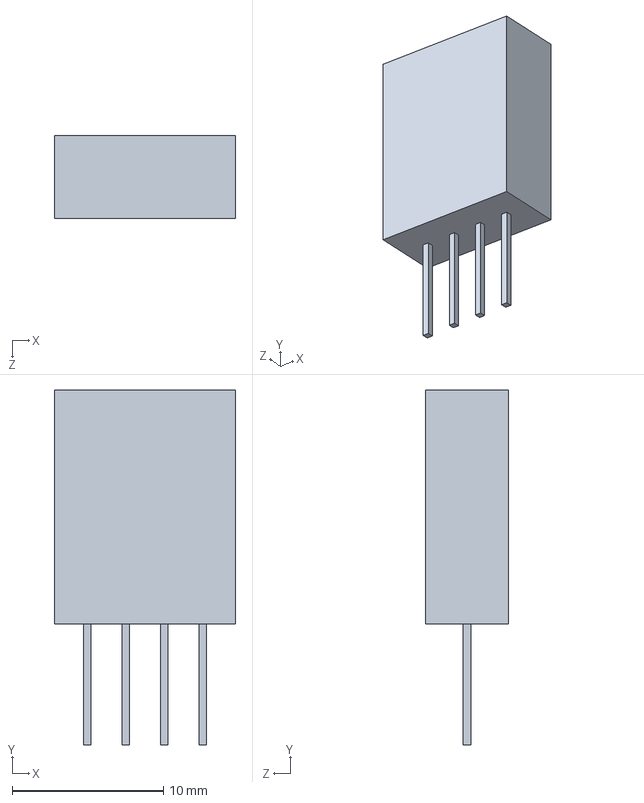
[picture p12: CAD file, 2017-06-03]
hardware/chasis/Modelo CAD/DHT11.SLDPRT
12.0 x 23.5 x 5.50 mm

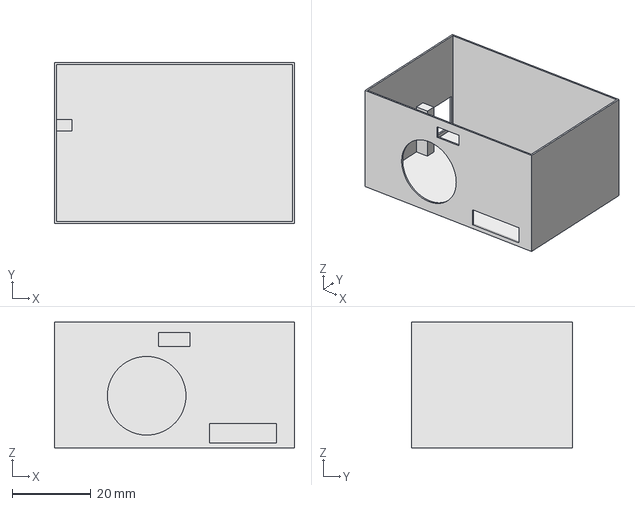
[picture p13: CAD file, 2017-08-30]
hardware/chasis/ChasisAQAFreecad/ChasisAQA.fcstd
61.0 x 41.0 x 32.0 mm

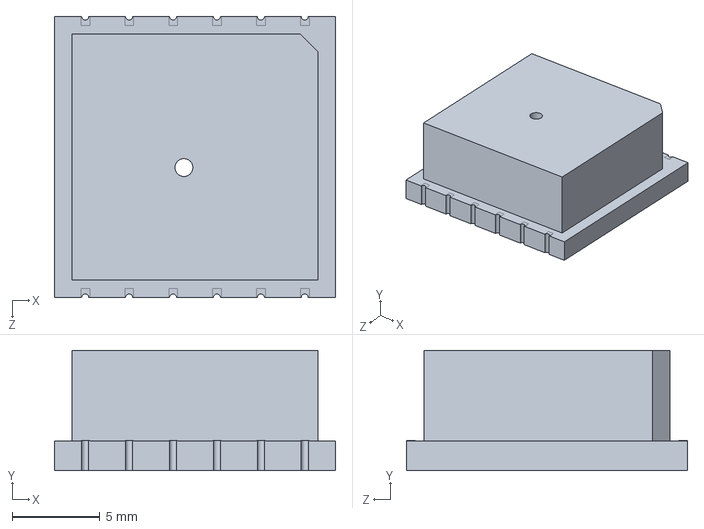
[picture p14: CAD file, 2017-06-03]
hardware/chasis/Modelo CAD/GPS.SLDPRT
16.0 x 6.85 x 16.0 mm

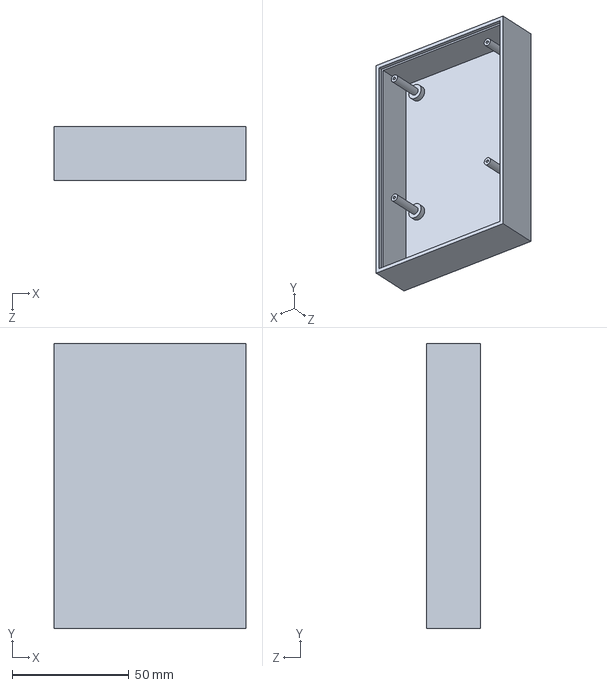
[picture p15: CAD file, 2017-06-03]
hardware/chasis/Modelo CAD/Tapa1.SLDPRT
82.0 x 122.0 x 23.0 mm

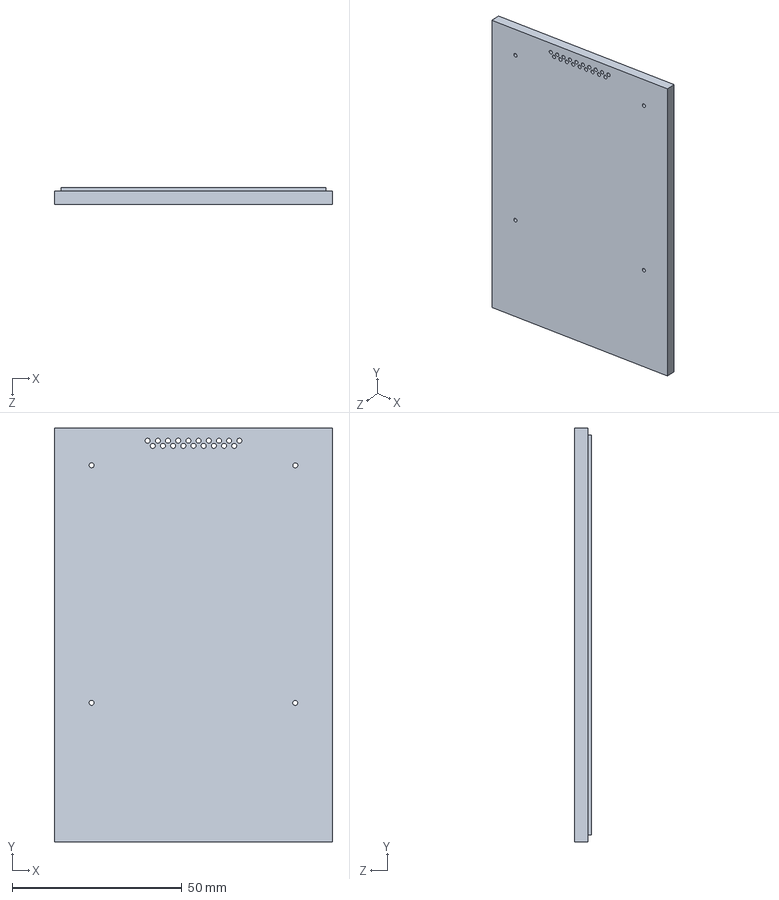
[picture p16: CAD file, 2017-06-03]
hardware/chasis/Modelo CAD/Tapa2.SLDPRT
82.0 x 122.0 x 5.00 mm

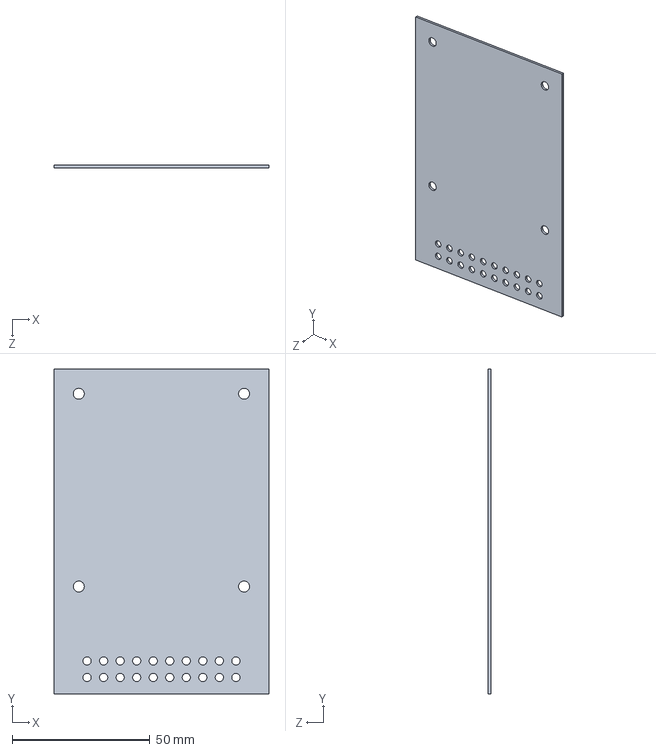
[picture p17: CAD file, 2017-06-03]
hardware/chasis/Modelo CAD/Tapa3.SLDPRT
78.0 x 118.0 x 1.00 mm

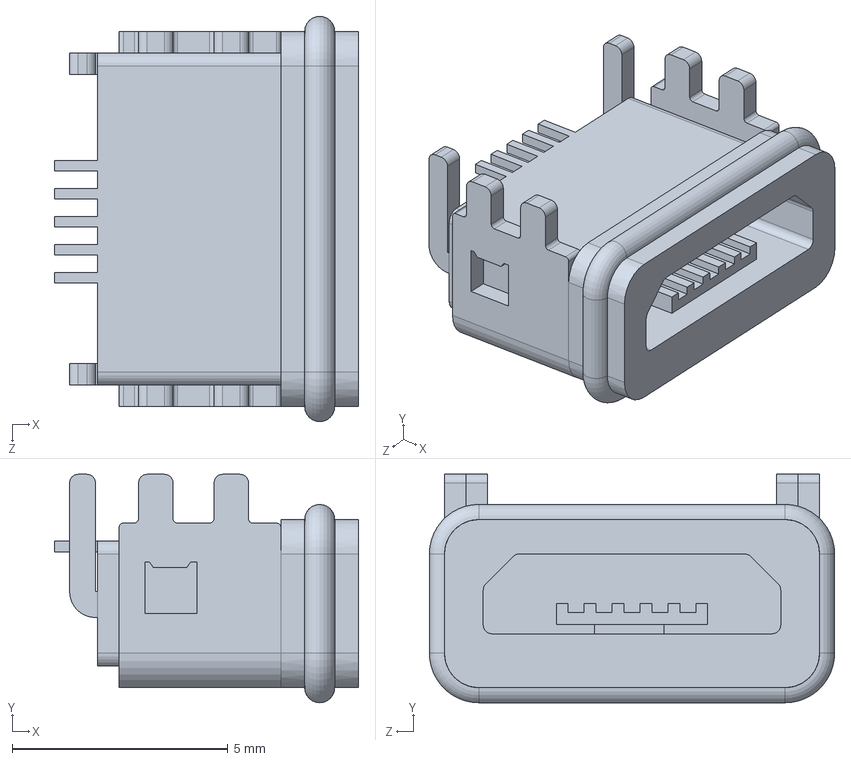
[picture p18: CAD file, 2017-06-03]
hardware/chasis/Modelo CAD/USB.sldprt
7.05 x 5.30 x 9.40 mm

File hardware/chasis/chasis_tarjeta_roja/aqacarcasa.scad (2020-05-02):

//no funciono la primera vez que se imprimo por tiempo por que quedo medio impreso 
difference(){
union(){
difference(){
union (){
large= 76;//las medidas de largo del sensor
largo = large+8;//cambio las variables de nombre para que las leea el codigo=84
deep=45;
profundo = deep+5;//50
 paredes=2;
 alto=20;
 tornilloyuno =  44.5;
cube([largo,profundo,paredes]);//base
//translate([0,0,2])//acrilico
//color("blue",0.7)//acrilico
//cube([large,4.7,0.2]);//acrilico
cube([largo,paredes,alto]);//lado  frente
translate([0,profundo,0])//lado trasero
cube([largo,paredes,alto]);//lado  trasero
cube([paredes,profundo,alto]);//lado 1 para micro usb
translate([largo,0,0])//lado 1 para mini usb
cube([paredes,profundo+2,alto]);//lado 1 para mini usb
}translate([-1,5,1])
cube([90,40,7]);}}
union(){
translate([67,39,-1])//grande
cylinder(r=4 ,h=3, $fn=100);}//grande
translate([77,44.5,-1])//pequño y2 x2
cylinder(r=2 ,h=3, $fn=100);
translate([9,44.5,-1])
//pequño y2 x1
cylinder(r=2 ,h=3, $fn=100);
//pequño y1 x2
translate([77,5,-1])
cylinder(r=2 ,h=3, $fn=100);
translate([30,-1,12])
cube ([15,4,7]);
translate([4,-1,16])
cube ([15,5,3]);
}

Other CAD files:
hardware/chasis/ChasisAQAFreecad/TapaChasisAQA.fcstd
hardware/chasis/Modelo CAD/ESP.SLDPRT
hardware/chasis/ChasisAQAFreecad/ChasisAQA.stl
hardware/chasis/ChasisAQAFreecad/TapaChasisAQA.stl

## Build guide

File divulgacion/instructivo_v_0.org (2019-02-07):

#+TITLE:      Instructivo
#+AUTHOR:     unloquer
#+EMAIL:      unloquer@gmail.com
#+INFOJS_OPT: toc:nil mouse:underline buttons:0 path:http://thomasf.github.io/solarized-css/org-info.min.js
#+HTML_HEAD: <link rel="stylesheet" type="text/css" href="http://thomasf.github.io/solarized-css/solarized-light.min.css" />
#+OPTIONS:    H:3 num:nil toc:t \n:nil ::t |:t ^:t -:t f:t *:t tex:t d:(HIDE) tags:not-in-toc
#+STARTUP:    align fold nodlcheck hidestars oddeven lognotestate
#+SEQ_TODO:   TODO(t) INPROGRESS(i) WAITING(w@) | DONE(d) CANCELED(c@)
#+LANGUAGE:   en
#+PRIORITIES: A C B
#+CATEGORY:   divulgacion

* Ambientación

** ¿Es la primera vez en un taller sobre la calidad del aire?
** ¿Qué se espera encontrar en este taller? 
** ¿Se ha ido a otro taller de calidad del aire? ¿Qué se ha encontrado?
** Lo que se puede y lo que no
*** Si se puede
**** Equivocarse
**** Jugar
**** Apasionarse por algún conocimiento o por alguna persona
**** Cuestionar
**** _____________
**** _____________
*** No se puede
**** Trollear (provocar reacciones emotivas en el otro)
**** Imponer una posición frente a un tema
**** __________
**** __________
* Nivel 1: Escala de colores

** Introducción 
    Camiones, carros, fábricas, emiten contaminantes pequeños que están en el aire y se mueven con el viento, 
***** ¿Cómo se puede saber de las zonas de mayor concentración de ese material particulado? 
***** ¿Cómo se puede visualizar?
***** ¿Porqué es importante que los ciudadanos midan la calidad del aire?
** ¿Se puede medir el aire que está alrededor?
   Imprime un mapa del barrio, sale a caminar con marcadores verde, naranja, rojo, morado y marrón, marca las mediciones en el mapa. 
***** Pasa cerca al mofle de un carro y observa el cambio en los colores.
***** ¿Qué pasa con las medicines en un semáforo cuando se acumulan carros intermitentemente?
***** ¿Cuáles son las zonas de mayor concentración de material particulado en mi cuadra? 
** Desde la posición de quien respira ¿existe diferencia entre la presencia del material particulado que hay a nivel atmosférico y las emisiones cercanas ?
** ¿Se puede ensamblar un sensor portable para medir la presencia (de particulas pequeñas) en el aire ?
***** PRACTICA: Poner a funcionar el sensor, 
      Partes: <sensor partículas> <microcontrolador> <leds> <pila> <hoja de papel> <colores>
****** Ensamble la pieza <sensor> en la pieza <microcontrolador>
****** Ensamble la pieza <leds> en la pieza <microcontrolador> 
****** Para encender, conecte el <microcontrolador> con el <adaptador USB>
****** Tome nota de los colores cada minuto en un papel durante 15 minutos
****** Experimentos
******* Enciende un fosforo cerca al sensor y toma nota de los cambios en la escala de colores.
******* En una habitación compara las mediciones cerrando ventanas y puertas con las que se observan con puertas y ventanas 
* Nivel 2: Tablero de mediciones
  Tener más fuentes de medición nos permite dimensionar la complejidad del fenómeno del aire, poder comparar esas mediciones entre sí puede revelar asuntos importantes para entender los fenómenos.

** Preguntas
*** ¿Cómo preparar nuestras mediciones para ser comparadas con otras?
*** ¿Cómo preparar las mediciones para ser consumidas por máquinas?¿Para qué?
** Medir mas variables 
*** PRÁCTICA: Agregar GPS 
**** Ensamble la pieza <gps> en la pieza <microcontrolador> 
***** Verifique;
      GPS bien conectado: <color>
      GPS bien localizado: <color>
** Visualizar y análizar las mediciones
*** PRÁCTICA: Conectarse al portal del sensor
    Este texto se tomaría de: https://comunidad.unloquer.org/t/como-conectar-el-aqa-dispositivo-de-medicion-a-wifi/76
*** PRÁCTICA: Poner el valor de PM2.5 en la matriz led
** Compartir las mediciones
*** PRÁCTICA: Conectar el sensor a internet
* Nivel 3 (extra): Explorar y aprovechar
** Cambiar el firmware
*** PRÁCTICA: Cambie el nombre del sensor
**** Instala el entorno platformio.io
**** Cambia el nombre del sensor en el archivo app.h
***** Verifica: compile (build) el proyecto con el cambio de nombre 
**** Sube el firmware al dispositivo
***** Conecta por el puerto mini USB.
***** Sube el firmware (upload).
***** Verifica: Se conecta por WiFi al dispositivo y verifica el nuevo nombre del sensor.
** Comunicar sensores entre sí
*** PRÁCTICA: Tansmite el valor de PM2.5 de un dispositivo con sensor de partículas a otro sin sensor de partículas.
* Nivel 4 (extra): Explorar ,aprovechar y personalisar 
** Escojer una caja de carton para todo el kit 
*** PRÁCTICA: dibujale o escribele el nombre del sensor
**** hagale huecos a la caja de carton  y que entre aire
**** colorée una cara
***** colerée dos caras del indicacion del la calidad de aire 
**** verifica que todo funcione y que te guste
***** diseña una cara que se pueda cambiar un dibujo   
***** colerea 2 caras  de valores alterados alrededor de unas planta en el jardin y  en la  cocina  
** Compartir las mediciones
*** PRÁCTICA: Conectar el sensor a internet
* Nivel 5 (extra): Explorar la ciudad y toma conciencia 
** sal a  un parque   
*** PRÁCTICA: toma mediciones a papel y lapiz por 2 minutos
**** hagale huecos a la caja de carton de  y que entre aire
**** sal a 2 restaurantes 
*** PRÁCTICA: toma mediciones a papel y lapiz por 2 minutos 
**** sal a un centro comercial
*** PRÁCTICA: toma mediciones a papel y lapiz por 2 minutos   
**** sal casa de 4 amigos y en cada una 
*** PRÁCTICA: toma mediciones a papel y lapiz por 2 minutos 
** Compartir las mediciones y hacer un promedio
*** PRÁCTICA: Conectar el sensor a internet
* Nivel 6 (extra): Explorar y aprovechar el sofware
** Cambiar el firmware
*** PRÁCTICA: Cambie el nombre del sensor
**** Instala el entorno platformio.io si no lo instalo  
**** Cambia el nombre del sensor en el archivo app.h
***** Verifica: compile (build) el proyecto con el cambio de nombre
** Cambiar el firmware comentado y descomentando  #esto es un comentario 
*** PRÁCTICA: comentando o descomentado la linea  #define MOBILE y buscarlo en el codigo
**** Sube el firmware al dispositivo
***** Conecta por el puerto mini USB.
***** Sube el firmware (upload).
***** Sube el firmware pero comentandolo #define MOBILE
***** Verifica: Se conecta por WiFi al dispositivo y verifica el nuevo nombre del sensor.
** Comunicar sensores entre sí
*** PRÁCTICA: Tansmite el valor de PM2.5 de un dispositivo con sensor de partículas a otro sin sensor de partículas.
* Nivel 7 (extra): identificar que  contamina ,los gases son contaminacion ?
** tareas 
*** ¿cuando hay un olor maluco hay contamicaion?
****¿ que indica el sensor?
*** ¿ que lugar de la casa es el mas contaminado  ?
****¿ es el mas oloroso?
***¿ un gas pude que cambie las particulas en el aire ?
* Nivel 8 (extra): cunto se demora en irse la contamniacion
**intente y responda
*** busque 3 respientes uno profundo y otro largo   y otro en promedio de lo profundo y largo   
*** meta el sensor en cada uno de los resipintes por el mismo tiempo y minimo 2 minutos 
****¿ que indica el sensor en cada respiente  y anote los colores y medidas de cada resipiente?
****¿ se fue la contaminacion? ¿en cuanto tiempo?
* Nivel 9 (extra): platas limpian el aire?
**investigue y comprueve compare 
***especies de plantas que limpien el aire
*** busque en internet plantas que limpin el aire y compare 
***platas que limpian purifican https://bit.ly/2Up1EMU https://bit.ly/2BU1DcE  
****pista solo hay un tipo de planta que limpia el aire de la polucion y se pude limpiar mediante el biomagentismo
   
* comparte tus resultados https://comunidad.unloquer.org/

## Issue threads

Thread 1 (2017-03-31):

Crear endpoints en el servidor para manejo de los datos

brolin, 2017-03-31:
¿Cómo vamos a manejar los datos en el servidor?
¿Cuál servidor vamos a usar?

son0p, 2017-11-28:
Se esta recibiendo mediciones en formato "Line Protocol" de influx en la llegada http://aqa.unloquer.org:8086/

Closed 2017-11-28.

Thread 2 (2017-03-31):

Diseñar estrategia de almacenamiento offline y envío de datos al servidor

brolin, 2017-03-31:
La memoria flash de los ESP tiene aproximadamente 3Megas de espacio para almacenamiento.

¿Cada cuánto debo registrar una muestra de datos?
¿Es necesario agregar una SD como otro nivel de almacenamiento, cuánto tiempo puedo guardar en la flash?
¿En qué momento debo enviar los datos, buscar permanentemente redes inalámbricas o descargar datos al celular y luego enviar desde el celular o cuándo llegue a un sitio establecido como HOME enviar datos?

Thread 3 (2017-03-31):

Diseñar sistema de alimentación recargable

brolin, 2017-03-31:
El sistema que se viene pensando es móvil, esto propone varios retos:

¿Cuál es la autonomía del dispositivo en términos de consumo de energía?
¿Qué tipo de baterías usar?
¿Se puede generar la energía que alimenta el sistema con páneles solares o una dínamo en una bicicleta?

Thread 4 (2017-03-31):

Diseñar circuitos cad para soldar dispositivos

brolin, 2017-03-31:
Diseñar circuitos cad para integrar los siguientes dispositivos:

- Sensor de partículas (hay varios tipos)
- Cerebro (esp8266)
- Sensor detector de gas
- Sensor de humedad y temperatura
- GPS l80 de quectel
- Batería
- Sensor de cantidad de luz
- Botones de control externo

miguelitoVargas, 2017-03-31:
De esto faltaría integrar la batería y los botones de control.... Hoy
espero sacar la tarjeta de manera exitosa, ya hice las correcciones de
diseño que vi salieron el viernes pasado. Nos olemos en un rato..... Sobro
diésel de hace 8 días?

El mar. 31, 2017 11:09 AM, "brolin" <notifications@github.com> escribió:

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

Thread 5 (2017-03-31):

Diseñar enclosure para disposición de los sensores

brolin, 2017-03-31:
Dadas las carecterísticas del sistema:

¿Cómo debe ser el contenedor? funciona a la intemperie?
¿Cuál materiales podemos usar?
¿Se hace uno genérico para bicicletas, personas a pie, personas en carro?

son0p, 2017-03-31:
Supongo que la caja debe ser muy resistente a la vibración, me pregunto si existe algún tipo de gelatina que no sea conductiva donde se pueda poner a "semi-flotar" el ensamble dentro de alguna caja dura que lo proteja del exterior y agarrada con velcro a uno de los tubos.
En mi trabajo se viaja mucho con elementos electrónicos, lo que más soporta el trajín es rellenar el interior de algo semiblando que impida cualquier posibilidad de movimiento.

Blando y compacto adentro, muy duro afuera.

  Alejo me habló ayer de las raíces de hongos (mycelium) con el que están haciendo empaques, podria servir de relleno?https://en.m.wikipedia.org/wiki/Mycelium

alejoduque, 2017-03-31:
Tambien esta la cera de abejas, pero claro, no sera tan resistente a plasticos y espumas

son0p, 2017-05-17:
@rvega propone hacer una carcasa en madera con una CNC ruteadora

miguelitoVargas, 2017-05-18:
que tipo de proceso llevaria la madera. No es una una buena idea madera por
lo siguiente:

a intemperie la va a deformar mucho, se expande contrae con el frio o
calor, termina quemandose por el sol y se quiebra/raja, no va a estar
totalmente sellado le va a entrar agua y se va a dañar

Siempre hemos pensado impresion 3D y plastico o acrilico en cortadora

On Wed, May 17, 2017 at 4:04 PM, Rafael Vega <notifications@github.com>
wrote:

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

son0p, 2017-09-01:
Se hizo un prototipo con la impresora 3D, al recibir sol dentro de un carro cerrado con alta temperatura se transformó
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

Se va a explorar poner tornillos con cabeza tipo knurled  y/o aumentar el grueso de las paredes dejando una trama delgada para la parte donde están los LED's

ojofranco, 2017-09-01:
Podemos hablar con Pablo  socio con Uber en  Falco Tecnologia para hacer
intercambio de saberes y herramientas. El es bueno  haciendo moldes y nos
puso a disposición una termo-formadora que el mismo construyo  a cambio me
imagino que le puede servir  poner a disposición la impresora 3d para el
sacar los moldes  madre que hoy día hace en madera.

Saludos

2017-09-01 10:20 GMT-05:00 federico lopez <notifications@github.com>:

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

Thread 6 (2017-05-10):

Interfaces (entre entidades)

son0p, 2017-05-10:
Podemos empezar a estructurar una forma clara, transparente y consistente para manejar las relaciones (flujos) entre entidades, entendidas como humanos, máquinas, instituciones, etc.

- Debería contener las maneras de reaccionar ante diferentes verbos (como referencia los verbos que usa el protocolo http, GET, POST, PUT, DELETE etc.)

- No es un sistema de tiempo real pues no se puede entregar una garantía de tiempo de respuesta.

- Debería soportar el anonimato y el consenso

Iniciamos una documentación en el documento interfaces.org basado en la estructura de http://r-s-g.org/LCL/

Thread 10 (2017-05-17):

Entender la forma como mide el sensor de laser

son0p, 2017-05-17:
@santiago encontró que el sensor se queda reportando la misma medida exacta por un tiempo, necesitamos entender esa situación y decidir si es así como queremos que funcione o corregirla.

son0p, 2017-08-08:
@brolin analiza la trama de datos y encuentra que hay datos diferentes a los que inician con 42 4E que son los únicos que lee el firmware.

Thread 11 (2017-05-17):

Cambiar el uso horario de las mediciones

son0p, 2017-05-17:
Hay que restarle 5 horas a la medida que esta guardando el sensor.

Documentar como se hace por si alguien en otro uso horario quiere participar en la red de mediciones

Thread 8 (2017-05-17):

Hacer que el color del led sea gradiente

son0p, 2017-05-17:
Ya se logró que el led reporte lectura de la partícula PM2.5 en tres colores (verde, amarillo, rojo)
Nos preguntamos si lograr una escala gradiente en el led puede mejorar la experiencia de lectura.
Acá se documenta como definir los colores https://github.com/FastLED/FastLED/wiki/Controlling-leds

son0p, 2017-10-06:
Carlos (SIATA) sugiere que el dispositivo tenga dos medidores uno del instante y otro según la especificación del AQI que creo que se calcula según esta ecuación: https://en.wikipedia.org/wiki/Air_quality_index#Computing_the_AQI

son0p, 2017-10-07:
Aquí hay una implementación para ESP8266 del Indice de calidad del Aire https://diyprojects.io/calculate-air-quality-index-iaq-iqa-dsm501-arduino-esp8266/#.Wdj3B6uQyCg

Closed 2020-01-21.

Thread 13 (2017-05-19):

Calibración

son0p, 2017-05-19:
Para comparar la medición del sensor laser con el homologado del SIATA tenemos unas mediciones a pocos metros de la estación de la Y (zona del tesoro) :

- 2017-05-18 a las 10:01, PM2.5 : 40
- 2017-05-18 a las 14:23, PM2.5 : 22

Alguien puede ayudar a evaluar los datos de esa estación ese día a esas horas y comparar las mediciones para tener una aproximación al margen de error que estamos viviendo.

estebanz01, 2017-06-01:
¿Qué metodología se tiene en mente para identificar dicha diferencia? Estaba pensando realizar una comparación de varianza respecto a lo que mide el SIATA o también un t-test comparando ambas distribuciones de contaminación (y suponiendo que las particulas tienen un comportamiento normal).

son0p, 2017-06-01:
Una muy básica, mirar las mediciones cercanas a alguna estación  del SIATA
y comparar la medida con la reportada por el SIATA a esa misma hora ese día.

Luego podríamos pedir al SIATA que ponga un display con  la medición del
instante en alguna de las estaciones y uno de se para ahí con su sensor y
mira las variaciones.

El 1 jun. 2017 8:55 AM, "Esteban Zapata Rojas" <notifications@github.com>
escribió:

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

son0p, 2017-10-07:
SIATA ofrece ayuda en la calibración de los sensores dejando un sensor por algunos días junto a una de las estaciones calibradas.

son0p, 2020-01-17:
Ya se están calibrando en la estación de la Torre del Ajedrez (S.I.A.T.A)

Closed 2020-01-17.

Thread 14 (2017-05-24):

Reportar valor de sensores en el ESSID de la red

brolin, 2017-05-24:
A través del ESSID de un AP creado por software en el firmware del ESP8266 se puede reportar el valor de los sensores principales.

Es crear el modo AP con la siguiente linea de código **WiFi.softAP(AP_NameString, password);** donde ssid es un String como  **String AP_NameString = "Calidad Aire PM2.5 " + PM25_value + "ug/m3";**

Tener en cuenta que el ESSID tiene un límite de 32 caracteres

son0p, 2017-06-17:
Resulto en el commit https://github.com/unloquer/AQA/commit/2984eaacd21a3aa8da679dc2ee3bbc219fc81d48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

son0p, 2017-06-21:
Debemos encontrar una manera de nombrar la red que se expone con un texto muy corto pero que comunique bien el mensaje de la calidad del aire en menos de 32 caracteres.

Una opción es hacer varias redes, ejemplo:

- aire-calidad: rojo
- part. pm25: 30 ug/m3

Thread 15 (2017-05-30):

Dimensiones del PCB y los sensores.

rvega, 2017-05-30:
Tienen links a los datasheets de los sensores y algún dibujo del PCB? Es para sacar dimensiones y medir bien el chasis.

brolin, 2017-05-30:
Hola,

envío por ahora el datasheet del sensor
http://www.rigacci.org/wiki/lib/exe/fetch.php/doc/appunti/hardware/raspberrypi/plantower-pms5003-manual_v2-3.pdf

el gps
http://www.quectel.com/UploadImage/Downlad/L80_Hardware_Design_V1.1.pdf

y del dht encontré este http://robocraft.ru/files/datasheet/DHT11.pdf

La tarjetica del ESP es aproximadamente del mismo tamaño del área
rectangular más grande del PMS5003

Saludos y gracias!

On Tue, May 30, 2017 at 11:21 AM, Rafael Vega <notifications@github.com>
wrote:

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

rvega, 2017-05-30:
No es claro en los dibujos del datasheet si el PMS5003 tiene huecos para tornillos o no... Me mandás fotos, porfa?

brolin, 2017-05-30:
No tiene huecos para tornillos, enseguida que desbarate el mouse te mando
las fotos

On Tue, May 30, 2017 at 12:14 PM, Rafael Vega <notifications@github.com>
wrote:

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

miguelitoVargas, 2017-05-31:
En el repositorio hay footprints del esp por si sirven tmb
El tamaño del sensor de polvo varía dependiendo entonces si la. Haces muy
justo con el de brolin no va a servir para el. Que yo tengo por ejemplo que
es un poquito más grande

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

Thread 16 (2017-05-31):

Mejorar recepción del GPS

son0p, 2017-05-31:
Uber menciona que si se usa una antena activa se puede mejorar la recepción.

son0p, 2017-06-16:
Se descarta esta opción por tamaño de la antena en conversación con Gustavo Galeano

Closed 2017-06-16.

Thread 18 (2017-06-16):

Errores en  la altura que reporta el GPS

son0p, 2017-06-16:
@josenobile señala altitudes sospechosas en la trama de datos:

lat,lng,date,hour,altitude,course,speed,humidity,temperature,pm1,pm25,pm10
6.263632,-75.597555,5/11/2017,06:13:41.00,1526.7,338.67,0.0,33.0,28.0,11,16,16
6.263632,-75.597555,5/11/2017,06:13:46.00,1526.7,338.67,0.0,32.0,29.0,10,15,15
6.263632,-75.597555,5/11/2017,06:13:52.00,1526.7,338.67,0.0,32.0,29.0,10,15,15
6.263632,-75.597555,5/11/2017,06:13:57.00,1526.7,338.67,0.0,32.0,29.0,10,15,15
6.2499,-75.593618,5/11/2017,22:59:34.00,150.6,103.42,28.54,38.0,23.0,53,75,82
6.249803,-75.593328,5/11/2017,22:59:39.00,152.7,118.22,25.0,38.0,23.0,53,75,82
6.249647,-75.593075,5/11/2017,22:59:45.00,155.0,135.6,18.82,38.0,23.0,53,75,82
6.249367,-75.592937,5/11/2017,22:59:50.00,157.7,156.37,23.37,38.0,23.0,53,75,82
6.249087,-75.592778,5/11/2017,22:59:56.00,159.6,149.09,20.67,38.0,23.0,53,75,82
6.248748,-75.592612,5/11/2017,23:00:02.00,155.9,149.59,20.52,38.0,23.0,53,75,82
6.248477,-75.592462,5/11/2017,23:00:08.00,157.8,148.75,18.56,38.0,23.0,41,55,61

Hay momentos donde se pasa de por ejemplo 1526 metros a 150 metros en la calle San Juan de Medellín.

josenobile, 2017-06-16:
Los GPS reportan la precision, este dato puede usarse para descartar datos con muy baja precision.

julibeth, 2017-06-16:
Medellín se encuentra 1.300 y 2.800 metros sobre el nivel del mar. Por lo visto hay casos que la altura no parece errada sino divida entre 10. Ejm:   150.6= 1506/10

josenobile, 2017-06-16:
Es correcto la apreciación de @julibeth Aunque eso indicaría el GPS tiene bugs, ya que no hace entrega consistente de los datos en cuanto a su representación.

son0p, 2017-10-05:
Vamos a cerrar este issue por que consideramos que los errores de las mediciones de altura se deben a los momentos en que el GPS no esta bien localizado.

Closed 2017-10-05.

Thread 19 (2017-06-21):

Textos de divulgación

son0p, 2017-06-21:
El proyecto esta siendo invitado a presentarse ante públicos que no están familiarizados con sensores, código, microcontroladores etc. necesitamos unos textos, ojalá infográficos que ayuden a contextualizar y ser comprendidos por estas personas, quizá un fanzine, o un volante que pueda ser entregado.

miguelitoVargas, 2017-06-21:
yo tengo pensado empezar a organizar algo en latex, bonito, para mas que
todo hacer un portafolio para los talleres, pero tambien se podria para
esto, igual se peden hacer en otra cosa, latex estoy acostumbrado es a
articulos, pero se que tiene de todo y hay plantillas que estan muy bien
diagramadas ya

2017-06-21 12:51 GMT-05:00 federico lopez <notifications@github.com>:

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

son0p, 2017-10-05:
Una crónica de Juan Sebastían  https://elbailarinsinson.blogspot.com.co/2017/09/causa-medio-y-encuentro.html

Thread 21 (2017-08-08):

No hay diagrama de conexiones para el wemos d1 mini

son0p, 2017-08-08:
Por el momento se puede adaptar la conexión con la gráfica http://wiki.unloquer.org/lib/exe/fetch.php?media=:personas:brolin:proyectos:montajeaqa.jpg

son0p, 2017-10-05:
un referente de como documentar la conexión incluida en el código

/*
 Shinyei PPD42NS Particle Sensor
 publish via serial and raspberry pi/python
 specification: http://www.sca-shinyei.com/pdf/PPD42NS.pdf
 pin 1 (grey)  -> Arduino GND
 pin 3 (black) -> Arduino 5V
 pin 2 (green) -> Arduino Pin 9
 pin 4 (white) -> Arduino Pin 8
 pin 5 (red)   -> unused!
*/

https://github.com/opendata-stuttgart/sensors-software/blob/6a55b6c2adebf3e3cbc0d38a257148ed8695a1bd/arduino/ppd42ns-sht10-serial/ppd42ns-sht10-serial.ino

Closed 2017-10-31.

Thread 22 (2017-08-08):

No hemos ensamblado sensores para instalaciones fijas

son0p, 2017-08-08:
No estamos aprovechando la posibilidad de tener sensores fijos midiendo 24 horas, idealmente igualar o superar el número de sensores de ciudadanos científicos.

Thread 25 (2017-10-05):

No tenemos una forma de diferenciar las emisiones de pm2.5 generadas por el portador del sensor

son0p, 2017-10-05:
Carlos (SIATA) señala

Hay un tema para pensar del correo sobre los sensores móviles puesto que hay dos miradas  complementarias e interesantes.

1. Una primera aplicación de  los sensores móviles pequeños que queremos impulsar y desarrollar en conjunto con un/loquer es  como sensores pasivos a bordo de vehiculos 0 o cerca a 0 emisiones o caminando garantizando que el vehiculo no altera la medición (en este caso no tiene mucho sentido que se incluya uso de motos,  taxis u otros vehículos).

2. Uso continuo (24/7) por personas de manera que se pueda estimar la calidad del ambiente en el que una persona normalmente vive/trabaja/se mueve/etc (en este caso pues si la persona se mueve en una moto tiene sentido que se mida desde ella).

son0p, 2018-10-16:
Se cierra por que se pretende dar lectura de lo que se respira, que es una combinación del material p articulado atmosférico con las emisiones, incluidas las emisiones del vehículo de quien lo porta.

Closed 2018-10-16.

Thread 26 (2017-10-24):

¿Cómo verificar el funcionamiento del GPS?

son0p, 2017-10-24:
Uno de los sensores deja una trama así:

```
federico,8.302080,0.000000,,,1.95,8.30,1.94,-1.00,-1.00,26,34,37
federico,8.302080,0.000000,,,1.95,8.30,1.94,-1.00,-1.00,26,33,34
federico,8.302080,0.000000,,,1.95,8.30,1.94,-1.00,-1.00,25,33,33
federico,8.302080,0.000000,,,1.95,8.30,1.94,-1.00,-1.00,21,30,30
```
Se ha probado al aire libre, con cielo abierto que en anteriores mediciones garantizaban la lectura del GPS.

¿Cómo verificar la conexión del GPS?

son0p, 2017-10-31:
Al parecer algunos GPS quedaron mal conectados, nunca se localizaban, revisamos 4 sensores, 2 tenian ese problema, los otros 2 funcionan bien, se los pasaremos a checho para que revise las conexiones.

Closed 2017-10-31.

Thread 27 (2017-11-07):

Problemas para borrar los datos de la Flash

son0p, 2017-11-07:
Algunos dispositivos han presentado problema para borrar los archivos de datalog.txt en ese caso descomentamos la función SPIFFS.format();
https://github.com/unloquer/AQA/blob/master/firmware/src/main.cpp#L29

Closed 2017-11-19.

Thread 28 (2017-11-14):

Dificultades para leer archivos grandes

son0p, 2017-11-14:
Durante el modo en que el ESP intenta conectarse a una red wifi hay una ventana para bajar el archivo datalog.txt accediendo a http//192.168.4.1/log pero la ventana de tiempo es, al parecer, muy corta y se congela la descarga para archivos grandes. (hasta 200k parece lograr bajar), aquí algunas de los métodos intentados:

*** esperar 1 minuto antes de resetear de nuevo =
***** conectarse a la segunda red creada
***** oprimir 20 segundos el boton reset
***** apagar dispositivo 5 minutos (trata de descargar las redes creadas en el cliente) =
***** Borrar las redes del ESP* en las redes conocidas ( descarga un porcentaje)
***** https://community.platformio.org/t/problem-connecting-esp8266-to-wifi-library-problem/610/6
***** Se considera la potencia, se intenta un cable más corto
***** FAIL Se considera usarlo sin conexion al computador, sino con adaptador a la pared FAIL
      CLOSED: [2017-11-10 Fri 07:06]
      - State "FAIL"       from              [2017-11-10 Fri 07:06] \\
      -       no se resuelve
***** FAIL Se intentan listar los archivos con fs_list_files(); // test
      CLOSED: [2017-11-10 Fri 07:22]
      - State "FAIL"       from "INPROGRESS" [2017-11-10 Fri 07:22]
****** entra al loop pero no lista los archivos
****** FAIL Se intenta abrir con SPIFFS.open("datalog.txt", "r");
       CLOSED: [2017-11-10 Fri 07:22]

       - State "FAIL"       from              [2017-11-10 Fri 07:22] \\
         no sale nada
***** FAIL Se intenta poner la wifiManager.setConfigPortalTimeout(180); // test
      CLOSED: [2017-11-10 Fri 07:56]
      - State "FAIL"       from              [2017-11-10 Fri 07:56] \\
        no permite descargar
***** INPROGRESS Se intenta poner mas larga la espera del modo wifi
****** FAIL Descarga casi completo el archivo de 2.2 megas
       CLOSED: [2017-11-10 Fri 07:36]
       - State "FAIL"       from              [2017-11-10 Fri 07:36] \\
         queda incompleto el archivo
****** FAIL se intenta comentar la linea ESP.reset() del condicional del blocking loop
       CLOSED: [2017-11-13 Mon 17:55]
       - State "FAIL"       from              [2017-11-13 Mon 17:55] \\
         nada
***** FAIL Se intenta acceder a la FLASH con  sudo dd if=/dev/ttyUSB0  of=/tmp/esp.image
      CLOSED: [2017-11-10 Fri 07:08]

      - State "FAIL"       from              [2017-11-10 Fri 07:08] \\
        al parecer solo lee la línea en ejecución
***** TODO No escanee redes solo inicie el servidor de archivos
***** DONE Instalo FTPServerSample https://github.com/nailbuster/esp8266FTPServer/tree/master/examples/FTPServerSample
      CLOSED: [2017-11-14 Tue 06:58]
****** FAIL Hago lectura corta e intento bajar por FTP
       CLOSED: [2017-11-14 Tue 07:11]
       - State "FAIL"       from              [2017-11-14 Tue 07:11] \\
         no se ve ningún archivo al conectarse por FTP después de hacer mediciones
***** INPROGRESS Dump de la memoria con esptool https://github.com/espressif/esptool#dumping-memory
****** TODO ¿cómo entender las direcciones de memoria descritas aquí? https://github.com/esp8266/esp8266-wiki/wiki/Memory-Map

son0p, 2017-11-17:
Por ahora estamos bajando los archivos grandes usando este firmware que solo contiene las librerías y funciones necesarias para la descarga : https://github.com/unloquer/WifiManagerDownloadData

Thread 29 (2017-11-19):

Problemas de con versión de librería <ESPAsyncTCP> v1.1.2

son0p, 2017-11-19:
Al intentar compilar una nueva clonación del repositorio sale un error en platformio-emacs:

```
.piolibdeps/ESPAsyncTCP_ID305/src/ESPAsyncTCP.cpp:78:28: error: invalid conversion from 'long int (*)(void*, tcp_pcb*, pbuf*, long int)' to 'tcp_recv_fn {aka signed char (*)(void*, tcp_pcb*, pbuf*, signed char)}' [-fpermissive]
tcp_recv(_pcb, &_s_recv);
^
```

La estructura  dependencias que genera es:

```
Library Dependency Graph
|-- <DHT sensor library> v1.3.0
|   |-- <Adafruit Unified Sensor> v1.0.2
|-- <FastLED> v3.1.6
|   |-- <EspSoftwareSerial>
|-- <DoubleResetDetector> v0.0.2
|-- <ESPAsyncWebServer> v1.1.0
|   |-- <ESPAsyncTCP> v1.1.2
|   |   |-- <ESP8266WiFi> v1.0
|   |-- <ESP8266WiFi> v1.0
|   |-- <Hash> v1.0
|-- <ESPAsyncWifiManager> v0.12
|   |-- <ESP8266WiFi> v1.0
|   |-- <DNSServer> v1.1.0
|   |   |-- <ESP8266WiFi> v1.0
|   |-- <ESPAsyncWebServer> v1.1.0
|   |   |-- <ESPAsyncTCP> v1.1.2
|   |   |   |-- <ESP8266WiFi> v1.0
|   |   |-- <ESP8266WiFi> v1.0
|   |   |-- <Hash> v1.0
|-- <Hash> v1.0
|-- <ESPAsyncTCP> v1.1.2
|   |-- <ESP8266WiFi> v1.0
|-- <ESP8266HTTPClient> v1.1
|   |-- <ESP8266WiFi> v1.0
|-- <TinyGPSPlus>
|-- <EspSoftwareSerial>
```

Comparandola con la estructura de una copia del repositorio que si compila bien se puede notar el uso de la versión **1.1.0 de ESPAsyncTCP** :

```
Library Dependency Graph
|-- <DHT sensor library> v1.3.0
|   |-- <Adafruit Unified Sensor> v1.0.2
|-- <FastLED> v3.1.6
|   |-- <EspSoftwareSerial>
|-- <DoubleResetDetector> v0.0.2
|-- <ESPAsyncWebServer> v1.1.0
|   |-- <ESPAsyncTCP> v1.1.0
|   |   |-- <ESP8266WiFi> v1.0
|   |-- <ESP8266WiFi> v1.0
|   |-- <Hash> v1.0
|-- <EspSoftwareSerial>
|-- <Hash> v1.0
|-- <ESPAsyncWifiManager> v0.12
|   |-- <DNSServer> v1.1.0
|   |   |-- <ESP8266WiFi> v1.0
|   |-- <ESPAsyncWebServer> v1.1.0
|   |   |-- <ESPAsyncTCP> v1.1.0
|   |   |   |-- <ESP8266WiFi> v1.0
|   |   |-- <ESP8266WiFi> v1.0
|   |   |-- <Hash> v1.0
|   |-- <ESP8266WiFi> v1.0
|-- <ESPAsyncTCP> v1.1.0
|   |-- <ESP8266WiFi> v1.0
|-- <ESP8266HTTPClient> v1.1
|   |-- <ESP8266WiFi> v1.0
|-- <TinyGPSPlus>
```

son0p, 2017-11-27:
El metodo que se ha usado es borrar todas las librerías de platformio
```
rm -rf .piolibdeps
```
Instalar la versión
```
pio lib install "ESPASyncTCP@1.0.1"
```
Luego al compilar se reinstalan las librerías restantes.

@brolin  esto lo hice de memoria, ¿esta correcto?

brolin, 2017-12-02:
Otra solución es actualizar la librería ESPAsyncWebServer a la última versión. Esto implica cambiar en **platformio.ini** en la variable **lib_deps** la dependencia a "ESP Async WebServer" (el creador de la librería la renombró con espacios)

Luego al compilar va a salir un error relacionado con **freertos/sphxxx.h** para solucionar esto borra el contenido de la carpeta **.piolibdeps/ESPAsynTCP_306/** pero no borres la carpeta **ESPAsyncTCP**

el comando que yo usé fue **rm -r .piolibdeps/ESPAsyncTPC_306/*** <- esto último es un asterico

después de esto compiló sin problemas

son0p, 2018-10-16:
Se cierra porque no se está usando esa librería por ahora.

Closed 2018-10-16.

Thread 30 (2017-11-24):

Hay glitches en el sensor de temperatura DTH11

son0p, 2017-11-24:
Una captura de pantalla muestra glitches en las mediciones de temperatura del sensor (línea lila); La medición de humedad, linea naranja,  del mismo sensor, también presenta glitches en los mismos momentos.

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

son0p, 2018-09-04:
No esta en el alcance del proyecto solucionar este asunto

Closed 2018-09-04.

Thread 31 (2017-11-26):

El punto de llegada de Influx y Chronograf no tienen ningún sistema de permisos

son0p, 2017-11-26:
Cualquiera puede hacer cualquier cosa por ejemplo lo que señala Oscar: "veo que tengo acceso a opciones que deberían ser solo de un admin como borrarDB y otras."

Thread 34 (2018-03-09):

¿Cómo integramos las mediciones de dos instancias de influxdb?

son0p, 2018-03-09:
Perdimos un servidor por unos días, en reacción reenviamos las mediciones a otro servidor, queremos integrar los datos de ambas mediciones.

Quizá podría hacerse usando backup y restore descritos aquí https://docs.influxdata.com/influxdb/v1.5/administration/backup_and_restore/

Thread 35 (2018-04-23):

¿De qué manera se puede expandir el alcance de la  lectura de un sensor?

son0p, 2018-04-23:
Hay casos donde el sensor debe quedar cerca a una ventana para que el GPS pueda localizarse, si el transito de personas es por otra zona que no tiene línea de vista con los leds del sensor se requiere un satelite (ESP+LED's) que pueda leer la medición de Internet o del mismo sensor para replicar la medición en sus leds.

alejoduque, 2018-04-23:
No entiendo bien la manera en como queda expresado el concepto de 'satelite'. Se refiere a un nodo intermedio que pueda hacer de puente o relay? Creo que si, es un ESP que funciona como repetidora.

son0p, 2018-04-23:
Puede ser un nodo de interconexión, o un nodo que tenga leds y replique la lectura de los leds de la unidad que si tiene sensor.
Son imaginados como unos ESP sin sensor pero con LED's.

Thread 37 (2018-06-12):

No tenemos alternativas de retroalimentación visual del dispositivo

son0p, 2018-06-12:
Se ha pensado en una matriz de leds que permita escribir el valor de la medición en el momento, o hacer animaciones en la gama de color de la medición.
También se ha pensado en un display.

son0p, 2018-09-04:
La matriz se integró al Kit

Closed 2018-09-04.

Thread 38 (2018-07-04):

¿Cómo optimizar el almacenamiento y envío de datos del sensor?

brolin, 2018-07-04:
Se busca lograr un formato optimizado como el que usan en https://earth.nullschool.net/ que es este https://raw.githubusercontent.com/cambecc/earth/master/public/data/weather/current/current-wind-surface-level-gfs-1.0.json

O en https://medium.com/vis-gl/wind-map-a58575f87fe3 que lo hacen binario https://github.com/uber/deck.gl/blob/5.3-release/showcases/wind/src/utils/load-data.js#L7

En este proyecto comprimen https://github.com/ourairquality/oaq-esp-open-rtos la información a almacenar en la Flash

jero98772, 2021-03-26:
se optimiso en  https://github.com/unloquer/aqav80/tree/AQAV80_modular , reduciendo el espacio reservado en memoria.
se remplaso unsigned int que reserva 4bytes  con un valor limite de 4294967295 ,  por unsigned short int que reserva 2bytes con un valor limite de 65535 .
se considero que un limite para la memoria que no afecte las mediciones

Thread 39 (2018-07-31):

Se está llenando el segmento de memoria .text al momento de hacer el enlazamiento del binario

brolin, 2018-07-31:
Al momento de compilar se presenta el siguiente error:

```
Linking .pioenvs/esp12e/firmware.elf
/home/brolin/.platformio/packages/toolchain-xtensa/bin/../lib/gcc/xtensa-lx106-elf/4.8.2/../../../../xtensa-lx106-elf/bin/ld: .pioenvs/esp12e/firmware.elf section `.text' will not fit in region `iram1_0_seg'
collect2: error: ld returned 1 exit status
*** [.pioenvs/esp12e/firmware.elf] Error 1
```
Si se comenta el **#define NUEVA_TARJETA** compila y la estructura de memoria que muestra del firmware es

```
Linking .pioenvs/esp12e/firmware.elf
Calculating size .pioenvs/esp12e/firmware.elf
Building .pioenvs/esp12e/firmware.bin
text       data     bss     dec     hex filename
372901     7228   32088  412217   64a39 .pioenvs/esp12e/firmware.elf
```
Se encuentra en internet esta información
- http://docs.platformio.org/en/latest/faq.html#program-memory-usage
- https://mcuoneclipse.com/2013/04/14/text-data-and-bss-code-and-data-size-explained/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

Esta situación se presenta con las últimas versiones de platformio, para la versión 1.4.0 no se presentaba.

brolin, 2018-08-02:
Revisar esta conversación https://gitter.im/esp8266/Arduino/archives/2016/08/23

brolin, 2018-08-03:
Se actualiza la versión de arduino para el esp a stage

Acá hay una discusión con un problema similar al que tenemos https://community.platformio.org/t/platformio-3-0-broke-all-my-esp8266-projects/747/7

Así se cambia a stage http://docs.platformio.org/en/latest/platforms/espressif8266.html#using-arduino-framework-with-staging-version

este commit https://github.com/unloquer/AQA/commit/75e1f22936b0eea936b7f667c2d78c9e7cede965 soluciona

Closed 2018-08-03.

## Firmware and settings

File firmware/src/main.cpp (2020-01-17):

#define MOBILE


#include "app.h"
#include <GDBStub.h>

int INIT = 1;
// const int DEBUG = 0;
const int READ_LOG = 1;
const int DELETE_LOG = 1;
const int SEND_LOG = 0;
const int SEND_RECORD = 1;

GPSData gps;
DHT11Data dht11;
PlantowerData plantower;
PlantowerData plantowerData;

FSInfo fs_info;
String readPosition();
void savePosition(String position);

void fs_info_print() {
  SPIFFS.info(fs_info);
  DMSG("totalBytes ");DMSG_STR(fs_info.totalBytes);
  DMSG("usedBytes ");DMSG_STR(fs_info.usedBytes);
  DMSG("blockSize ");DMSG_STR(fs_info.blockSize);
  DMSG("pageSize ");DMSG_STR(fs_info.pageSize);
  DMSG("maxOpenFiles ");DMSG_STR(fs_info.maxOpenFiles);
  DMSG("maxPathLength ");DMSG_STR(fs_info.maxPathLength);
}

void fs_delete_file() {
  //SPIFFS.format(); // descomentar esta línea si hay algo que no se puede borrar en la memoria flash
  // Assign a file name e.g. 'names.dat' or 'data.txt' or 'data.dat' try to use the 8.3 file naming convention format could be 'data.d'
  char filename [] = "datalog.txt";                     // Assign a filename or use the format e.g. SD.open("datalog.txt",...);

  if (SPIFFS.exists(filename)) SPIFFS.remove(filename); // First blu175.mail.live.com in this example check to see if a file already exists, if so delete it
}

#include <DoubleResetDetector.h>

// Number of seconds after reset during which a
// subseqent reset will be considered a double reset.
#define DRD_TIMEOUT 100

// RTC Memory Address for the DoubleResetDetector to use
#define DRD_ADDRESS 0

DoubleResetDetector drd(DRD_TIMEOUT, DRD_ADDRESS);
void readLog();

// void readLog() {
//   DMSG_STR("Reading log ...");
//   File file = SPIFFS.open("datalog.txt", "r");
//   String line = "";
//   if (!file) DMSG_STR("file open failed");  // Check for errors
//   while (file.available()) {
//     wdt_disable();
//     // Read all the data from the file and display it

//     char c = file.read();
//     if(c == '\r') {
//       if(!line.endsWith("NULL")) {
//         DMSG_STR("Posting: "+line);
//         if(SEND_RECORD) {
//           postCsv("http://45.55.34.88:3000/api/v0/air.csv", line);
//         }
//       }

//       // Discard the \n, which is the next byte
//       file.read();
//       line = "";
//     } else {
//       line += String(c);
//     }
//     wdt_enable(1000);
//   }
// }

void deleteLog() {
  DMSG_STR("Deleting log");
  SPIFFS.remove("datalog.txt");
}

void sendLog() {
  String url = "http://192.168.0.18:3000/api/v0/air.csv";
  postCsvFile(url, "log");
}


void syncLog() {
  if(!INIT) { return; }
  INIT = 0;

  if(READ_LOG) {
    readLog();
  }

  if(SEND_LOG) {
    sendLog();
  }

  if(DELETE_LOG) {
    deleteLog();
  }
}

void fs_list_files(){
  Dir dir = SPIFFS.openDir("/");
  while (dir.next()) {
    DMSG(dir.fileName());
    File f = dir.openFile("r");
    DMSG_STR(f.size());
  }
}

// #include <stdio.h>
// #include <time.h>
#include <Time.h>
#include <TimeLib.h>

//https://arduino.stackexchange.com/questions/1013/how-do-i-split-an-incoming-string#1033
String getValue(String data, char separator, int index)
{
  int found = 0;
  int strIndex[] = { 0, -1 };
  int maxIndex = data.length() - 1;

  for (int i = 0; i <= maxIndex && found <= index; i++) {
    yield();
    if (data.charAt(i) == separator || i == maxIndex) {
      found++;
      strIndex[0] = strIndex[1] + 1;
      strIndex[1] = (i == maxIndex) ? i+1 : i;
    }
  }
  return found > index ? data.substring(strIndex[0], strIndex[1]) : "";
}

void readLog() {
  DMSG_STR("Reading log ...");
  fs::File file = SPIFFS.open("datalog.txt", "r");
  if(readPosition().toInt() > 0) file.seek(readPosition().toInt(),SeekSet);
  DMSG_STR("Initial position " + readPosition());
  String line = "", line2send;
  int linesCnt = 0;
  String device,lat,lng,date,hour,altitude,course,speed,humidity,temperature,pm1,pm25,pm10;
  String y,m,d,h,mi,s;
  int Year,Month,Day,Hour,Minute,Second;
  if (!file) DMSG_STR("file open failed");  // Check for errors
  while (file.available()) {
    yield();
    wdt_disable();
    // Read all the data from the file and display it

    char c = file.read();
    int field;
    if(c == '\r') {
      if(!line.endsWith("NULL")) {
        //pm10
        pm10 = line;
        //DMSG("pm10=");DMSG(line);DMSG(" ");DMSG_STR(field);

        tmElements_t t;
        time_t t_of_day;
        t.Year = CalendarYrToTm(Year);
        t.Month = Month;
        t.Day = Day;
        t.Hour = Hour;
        t.Minute = Minute;
        t.Second = Second;
        //t.tm_isdst = -1;        // Is DST on? 1 = yes, 0 = no, -1 = unknown
        t_of_day = makeTime(t);
        //t_of_day = mktime(&t);

        linesCnt ++;

        line2send += device + STR_COMMA + F("id=") + device + F(" lat=") + lat + F(",lng=") + lng + F(",altitude=") + altitude + F(",course=") + course + F(",speed=") + speed + F(",humidity=") + humidity + F(",temperature=") + temperature + F(",pm1=") + pm1 + F(",pm25=") + pm25 + F(",pm10=") + pm10 + F(" ") + t_of_day + F("\n");

        if(linesCnt == 40) { // que pasa si la última tanda tiene menos de 50 líneas??
          DMSG_STR(linesCnt);
          //DMSG(line2send);
          // DMSG_STR("Free Memory: "+String(ESP.getFreeHeap()));
          savePosition((String) file.position());
          DMSG_STR("File position "+ String(file.position())); // La posición de memoria donde va leyendo el archivo, almacenarla para continuar desde acá
          post2Influx("http://aqa.unloquer.org:8086/write?db=aqamobile&precision=s", line2send);
          line2send = "";
          linesCnt = 0;
        }
      }

      // Discard the \n, which is the next byte

      field = 0;
      file.read();
      line = "";
    } else {
      if(c == ',') {
        switch(field) {
        case 0:
          //device
          device = line;
          //DMSG("device=");DMSG(line);DMSG(" ");DMSG_STR(field);
          break;
        case 1:
          //lat
          lat = line;
          //DMSG("lat=");DMSG(line);DMSG(" ");DMSG_STR(field);
          break;
        case 2:
          //lng
          lng = line;
          //DMSG("lng=");DMSG(line);DMSG(" ");DMSG_STR(field);
          break;
        case 3:
          //date
          date = line;
          //DMSG("date=");DMSG(line);DMSG(" ");DMSG_STR(field);
          y = getValue(line, '/', 2);
          d = getValue(line, '/', 1);
          m = getValue(line, '/', 0);
          Year=y.toInt();
          Month=m.toInt();
          Day=d.toInt();

          break;
        case 4:
          //hour
          hour = line;
          //DMSG("hour=");DMSG(line);DMSG(" ");DMSG_STR(field);
          s = getValue(line, ':', 2);
          mi = getValue(line, ':', 1);
          h = getValue(line, ':', 0);
          Hour = h.toInt();
          Minute = mi.toInt();
          Second = s.toInt();
          break;
        case 5:
          //altitude
          altitude = line;
          //DMSG("altitude=");DMSG(line);DMSG(" ");DMSG_STR(field);
          break;
        case 6:
          //course
          course = line;
          //DMSG("course=");DMSG(line);DMSG(" ");DMSG_STR(field);
          break;
        case 7:
          //speed
          speed = line;
          //DMSG("speed=");DMSG(line);DMSG(" ");DMSG_STR(field);
          break;
        case 8:
          //humidity
          humidity = line;
          //DMSG("humidity=");DMSG(line);DMSG(" ");DMSG_STR(field);
          break;
        case 9:
          //temperature
          temperature = line;
          //DMSG("temperature=");DMSG(line);DMSG(" ");DMSG_STR(field);
          break;
        case 10:
          //pm1
          pm1 = line;
          //DMSG("pm1=");DMSG(line);DMSG(" ");DMSG_STR(field);
          break;
        case 11:
          //pm25
          pm25 = line;
          //DMSG("pm25=");DMSG(line);DMSG(" ");DMSG_STR(field);
          break;
        case 12:
          //pm10
          pm10 = line;
          //DMSG("pm10=");DMSG(line);DMSG(" ");DMSG_STR(field);
          break;
          //default:
        }
        line = "";
        field++;
      } else {line += String(c);}
    }
    wdt_enable(1000);
  }
}

void setup() {
  Serial.begin(115200);
  DMSG_STR("\nStarting ...");

  pinMode(D0, OUTPUT); digitalWrite(D0, HIGH); // https://github.com/esp8266/Arduino/issues/1622#issuecomment-347165350

  SPIFFS.begin();
  setupLeds();
  setupGPS();
  setupPlantower();
  setupDHT11();
  //fs_delete_file();  // descomentar para borrar la memoria
  fs_info_print();
  //fs_list_files();

#ifdef MOBILE
  DMSG_STR("MOVIL");
  if (drd.detectDoubleReset()) {
    DMSG_STR("Connecting to network ...");
    setupWifi();
    readLog();
    fs_delete_file();
    savePosition("0");
  }
  //   WiFi.mode(WIFI_AP);
  //reportWiFi(30);
#else
  DMSG_STR("FIJO");
  setupWifi();
#endif
}

int i = 0;

void loop() {

#ifndef MOBILE
  if (WiFi.status() != WL_CONNECTED) {
    delay(5000);
    digitalWrite(D0, LOW); delay(100); // from here https://github.com/esp8266/Arduino/issues/1622#issuecomment-347165350
    return;
  }
#endif

  gps = getGPSData();
  plantower = getPlantowerData();
  dht11 = getDHT11Data();
  if(plantower.ready) {
    plantowerData = plantower;
    if(plantowerData.ready) {
      ledParticulateQuality(plantowerData);
      //reportWifi( plantower.pm25);
      //if(gps.ready) {
#ifdef MOBILE
        ledParticulateQualityStreamming(plantowerData);
        save();
#else
        ledParticulateQualityStreamming(plantowerData);
        String frame = influxFrame();
        DMSG_STR(frame);
        //post2influx("http://159.203.187.96:8086/write?db=aqaTest", frame);
        post2Influx("http://aqa.unloquer.org:8086/write?db=aqa", frame);
        i++;
#endif
        //}
    }
  }


#ifdef MOBILE
  drd.loop();
#else
  if(i >= 30){
    i = 0;
    digitalWrite(D0, LOW); delay(100);;
  }
#endif
}

String readPosition() {
  char filename [] = "position.txt";                     // Assign a filename or use the format e.g. SD.open("datalog.txt",...);
  File file = SPIFFS.open(filename, "r");
  if (!file) {
    DMSG_STR("file open failed");   // Check for errors
    return "-1";
  }
  String p = file.readString();
  return p;
}

void savePosition(String position) {
  char filename [] = "position.txt";                     // Assign a filename or use the format e.g. SD.open("datalog.txt",...);
  File file = SPIFFS.open(filename, "w+");
  if (!file) {
    DMSG_STR("file open failed");   // Check for errors
    return;
  }

  //DMSG_STR("Dentro de saveposition " + position);
  file.println(position);
  file.close();
}


void save() {
  char filename [] = "datalog.txt";                     // Assign a filename or use the format e.g. SD.open("datalog.txt",...);
  File file = SPIFFS.open(filename, "a+");        // Open a file for reading and writing (appending)
  if (!file) {
    DMSG_STR("file open failed");   // Check for errors
    return;
  }

  String frame = csvFrame();
  DMSG_STR(frame);
  file.println(frame);
  file.close();
}

String csvFrame() {
  /* CSV is ordered as:
     "id","lat","lng","date","time","altitude","course","speed","humidity",
     "temperature","pm1","pm25","pm10"
  */

  // First datum is the sensor_id
  String frame = SENSOR_ID + STR_COMMA;

  // Add GPS data
  char strlat[25],strlng[25];
  dtostrf(gps.lat, 3, 6, strlat);
  dtostrf(gps.lng, 3, 6, strlng);

  frame += strlat + STR_COMMA;
  frame += strlng + STR_COMMA;
  frame += gps.date + STR_COMMA;
  frame += gps.time + STR_COMMA;
  frame += gps.altitude + STR_COMMA;
  frame += gps.course + STR_COMMA;
  frame += gps.speed + STR_COMMA;

  //Add DHT11 data
  if(dht11.ready) {
    frame += dht11.humidity + STR_COMMA;
    frame += dht11.temperature + STR_COMMA;
  } else {
    frame += STR_NULL + STR_COMMA + STR_NULL + STR_COMMA;
  }

  // Add Plantower data
  if(plantower.ready) {
    frame += plantower.pm1 + STR_COMMA;
    frame += plantower.pm25 + STR_COMMA;
    frame += plantower.pm10;
  } else {
    frame += STR_NULL + STR_COMMA + STR_NULL + STR_COMMA + STR_NULL;
  }

  return frame;
}

String influxFrame() {
  /* CSV is ordered as:
     "id","lat","lng","date","time","altitude","course","speed","humidity",
     "temperature","pm1","pm25","pm10"
  */

  // First datum is the sensor_id
  String frame = SENSOR_ID + STR_COMMA + F("id=") + SENSOR_ID +  STR_SPACE;

  // Add GPS data
  char strlat[25],strlng[25];
  dtostrf(gps.lat, 3, 6, strlat);
  dtostrf(gps.lng, 3, 6, strlng);
  frame += F("lat=");
  //frame += strlat + STR_COMMA;
  frame += 6.230127 + STR_COMMA; // hard coded latitude lat 
  frame += F("lng=");
  //frame += strlng + STR_COMMA;
  frame += -75.593703 + STR_COMMA;// hard coded longitude lng
  //frame += gps.date + STR_COMMA;
  //frame += gps.time + STR_COMMA;
  frame += F("altitude=");
  frame += gps.altitude + STR_COMMA;
  frame += F("course=");
  frame += gps.course + STR_COMMA;
  frame += F("speed=");
  frame += gps.speed + STR_COMMA;

  //Add DHT11 data
  //if
  frame += F("humidity=");
  frame += dht11.humidity + STR_COMMA;
  frame += F("temperature=");
  frame += dht11.temperature + STR_COMMA;
  // } else {
  //   frame += "humidity=" + STR_NULL + STR_COMMA + "temperature=" + STR_NULL + STR_COMMA;
  // }

  // Add Plantower data
  // if
  frame += F("pm1=");
  frame += plantower.pm1 + STR_COMMA;
  frame += F("pm25=");
  frame += plantower.pm25 + STR_COMMA;
  frame += F("pm10=");
  frame += plantower.pm10;
  // } else {
  //   frame += "pm1=" + STR_NULL + STR_COMMA + "pm25=" + STR_NULL + STR_COMMA + "pm10=" + STR_NULL;
  // }

  return frame;
}

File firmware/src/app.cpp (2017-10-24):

/*#include "app.h"

GPSSensor *gps;

void setup() {
  Serial.begin(115200);
  delay(1000);

  static const int gpsRXPin = 13, gpsTXPin = 7;
  static const uint32_t GPSBaud = 9600;

  // SoftwareSerial gpsSerial(gpsRXPin, gpshTXPin);
  // GPSSensor gpsSensor(&gpsSerial);

  // GPSSensor gpsSensor(gpsRXPin, gpsRXPin);

  GPSSensor gpsSensor = GPSSensor();

  gpsSensor.begin();
  gps = &gpsSensor;
}

void loop() {
  // Serial.print(".");
  wdt_disable(); // Disable watchdog
  gps->read();
  // ;
  delay(1000);
  Serial.print("-");
  // Serial.println(gps->data.lat);
  // Serial.println(gps->data.lng);
}
*/

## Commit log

2017-04-01 Lee datos de temperatura y humedad de DHT11, datos de lat, lon de gps y datos de concentración de partículas PM2.5 de sensor GP2Y1010AU a través de ADC externos ADS1115
2017-04-03 Hace varios experimentos para el manejo del GPS
2017-04-03 Almacena trama de datos en la memoria flash del esp
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2017-04-04 Cambia variable de concentración de partículas de int a float
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2017-05-13 Agrega led indicador de la calidad del aire
2017-05-17 Crea función para enviar a través de post archivo con datos
2017-05-17 se puso el led intermintente con tiempos variables según escala de calidad de aire
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2017-05-30 Primera versión del chasis
    [Ensamble CAM.SLDASM, Ensamble.SLDASM, PCB.SLDPRT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]
2017-05-30 estructura información para presentación del 15 de junio
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2017-05-31 Medidas mas reales, GPS, humedad, ESP.
    [DHT11.SLDPRT, ESP.SLDPRT, Ensamble.SLDASM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]
2017-06-03 Ya no se necesitan los pines de checho
2017-06-12 agrega categoría al ledger para filtrar costos, agrega items a divulgación
2017-06-13 cambia secciones para tener pausas en cada una y explicar mejor lo que se quiere mostrar
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2017-06-16 agrega muestra de la trama de datos en el readme, expande las notas de evento de divulgacion
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2017-06-16 Agrega funcionalidad que reporta valor pm2.5 a través del ssid
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2017-06-28 integra inventario y presupuesto en el mismo cuaderno de ledger
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2017-07-07 inicia proyecto ladrillera, repara costos despues de merge
2017-07-08 define el problema como problema, estructura las fases
2017-07-11 Update propuesta_ladrillera.md
    Mis aportes iniciales para la propuesta.
    Ricardo Z
2017-07-11 agrega presupuesto fase 2, elimina columnas presupuesto fase 1,
    [presupuesto_fase2.csv, propuesta_ladrillera.csv]
2017-07-11 elimina negrilla, no traduce bien a md
    [propuesta_ladrillera.csv]
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2017-08-18 No había un presupuesto para la red de huerteros, no se había implementado la definición de Dolar como moneda
2017-08-29 No se habían agregado transacciones de gps, pinzas y kit mini mandril
2017-08-30 Agrega carpeta con el diseño del chasis
    [ChasisAQA.fcstd, ChasisAQA.stl, TapaChasisAQA.fcstd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]
2017-09-10 Agrega variación a la tapa del chasis
    [TapaChasisAQA.fcstd, TapaChasisAQA.stl]
2017-09-10 Integra desarrollo de gaviria al trunk inicial de desarrollo
2017-10-11 no aparecian inventarios iniciales de plantower y leds
2017-10-11 No estaban implementadas las formulas en el presupuesto inicial
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2017-10-22 Actualiza costos por la venta de 2 GPS+ESP
2017-10-24 no se podían borrar cosas de la flash que ocupaban espacio, se propone la opción de formatear la flash
2017-10-24 unos experimentos con el gps no permitían que entrar a la función setup, se quitó la impresión del timestamp
2017-10-31 se revisan transacciones de inventario, se ingresa aporte de francisco y luis
2017-11-11 Agrega compra de 10 sensores, y mensualidad de Digital Ocean
2017-11-23 El frame que conforma la trama que se graba en csv no es compatible con influxdb, se formatean los datos para ser compatibles con influxdb y se hace una función que haga post de las mediciones
2017-11-24 Se prepara el merge reponiendo unas funciones borradas
2017-11-26 se direcciona el post al influx de unloquer
2018-01-20 Prueba librería https://github.com/tzapu/WiFiManager a ver si mejoran los problemas de conectividad del sensor
    [main.cpp, wifi.cpp]
2018-02-02 Agrega función para enviar datos en formato lineprotocol
2018-02-16 cambia patrón de leds cuando esta localizado el GPS, resetea cada 30 mediciones intentando mejorar estabilidad en la conexión
    [main.cpp]
2018-02-18 ejecuta ESP.reset() luego de algunos envíos, ayuda en redes inestables
    [main.cpp]
2018-02-19 comentarios en el main.cpp para creación de defines
2018-02-19 Corrige pines de los leds
2018-02-19 Deshabilita double reset para poder tenre el esp reiniciándose continuamente
    [main.cpp]
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2018-03-13 permite coordenadas fijas, cambia colores en dos funciones del led
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2018-03-19 agrega un generador de mediciones moviles ficticias para probar el mapa
2018-04-01 agrega script para recrear datos de sensores, guardados en archivos
2018-04-01 agrega script para recrear datos de sensores, guardados en archivos 2
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2018-04-19 agrega texto de divulgación para evento como me sumo
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2018-05-15 Habilita definiciones para hacer de manera opcional debug, leds para nueva tarjeta y si el funcionamiento es móvil o fijo
2018-05-29 Almacena la posición de lectura del archivo de datos mientras está envíando al servidor, si no se completa el envío en el próximo intento comienza donde iba y no desde el principio
2018-06-27 se inicia boceto de instructivo para acompañar el kit pedagógico
2018-07-04 divide el instructivo en tres niveles y plantea temáticas para cada uno
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2018-07-31 Actualiza platformio.ini para que funcione el proyecto con última versión de platformio
2018-07-31 Agrega diseño de hardware básico en kicad
    [aqa.kicad_pcb, aqa.sch]
2018-08-03 Resuelve problemas de compilación al actualizar platformio, usa la versión stage del sdk y la versión de desarrollo de wifimanager
    [main.cpp]
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2018-08-17 cambia la dependencia a WiFiManager por error en compilación
2018-09-27 añadir nuevos niveles a al instructivo correcion vista bonita y correcion de la correcion mia
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2018-10-11 limita a dos LEDS la alerta visual mientras se arregla el encendido de tres LEDS que a veces se queda encendido o apagado alguno
2018-10-13 Arregla parpadeo de leds
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2019-02-07 Deshabilita wifimanager para realizar la conexión wifi con los parámetros quemadosen archivo wifi.cpp. Las coordenadas GPS también están quemadas en la función influxFrame de main.cpp
2019-02-08 Reinicia cuando se encuentra un error en el envío de datos http y cambia los ESP.reset() por void setup() { pinMode(D0, OUTPUT); digitalWrite(D0, HIGH); } digitalWrite(D0, LOW); delay(100); tomado de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
    [main.cpp, wifi.cpp]
2020-01-17 solucion a issu 8 color gradiente de los leds mientras mas intenso el color mas contaminacion y menos menos contaminacion respetando la escla del ica
2020-01-17 actualisando AQA para hacer fork para dar solucion a issu del color gradiente
    [aqa.kicad_pcb, aqa.sch]
2020-01-19 corrigiendo pequeño error de sintaxis
    [plantower.cpp]
2020-05-02 actualisar readme y añadir diseños 3d para la tarjeta roja
    [aqacarcasa.scad, aqacarcasa.stl]
